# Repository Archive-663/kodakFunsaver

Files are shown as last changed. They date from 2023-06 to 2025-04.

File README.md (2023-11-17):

# Lot no.004 | A Rehousing for Kodak Funsaver Lenses
Unexpect the Expected. digi-Process C-41 Lens Adapter for Kodak Funsaver

The Loudness of Noise

You hate waiting for film to be processed and wish it was instant. But I want that analogue feel without the analogue burden.

I keep these memories, looking through old photos with a wash of nostalgia. Each tell a different story, but the same one every time.

The photographs, while taken quickly and blasé, tell a story once only told through cheap disposable cameras. While you think they are poor imitations, I see them as an homage to a time when we were children documenting our family trips. This lens adapter is a return to our childlike innocence and spontaneity.

The loudness of noise is a link to the past. A link to a time when we waited for the one hour film developer to process our memories.

Nostalgia — it sells.

### Features:
- Breech-lock mounting ring for DSLR/SLR cameras
- Standard mounting for Mirrorless cameras
- 30mm focal length
- Fixed ~f11 aperture
- Available in: Canon EF, EF-S, FD, RF; Fuji X; Leica M; M42; Nikon F DX, F FX, Z FX; Sony E, FE

### Helpful Links:
- [Kodak FunSaver Disassembly](https://www.youtube.com/watch?v=eMyq5sUIDkU)

- [Kodak FunSaver Lens Removal](https://www.youtube.com/watch?v=mniP1P2PrpM)

- [Kodak FunSaver Lens Adapter Assembly](https://www.youtube.com/watch?v=7Ed5-oDCAb8)

### Help support Archive 663 with a dontation or monthly sub


### Samples

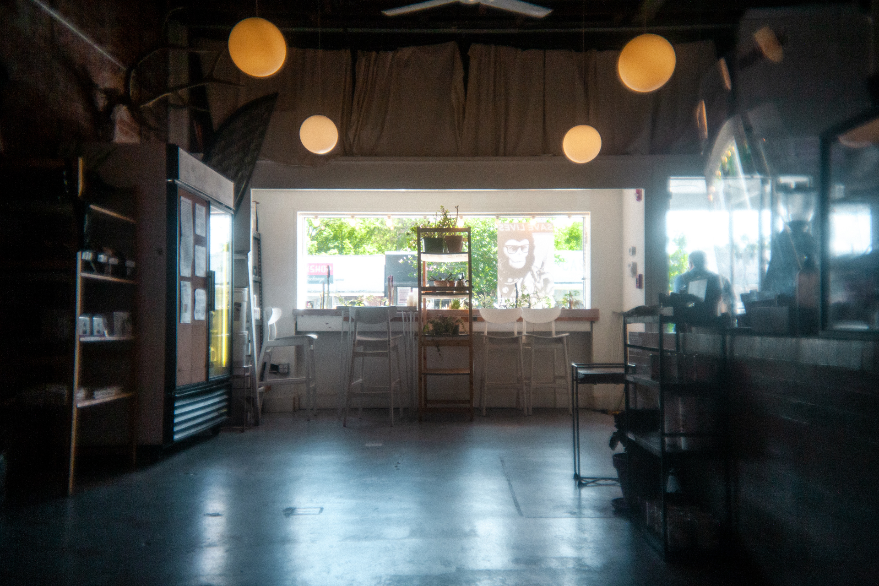
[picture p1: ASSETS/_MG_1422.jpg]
Sample 001

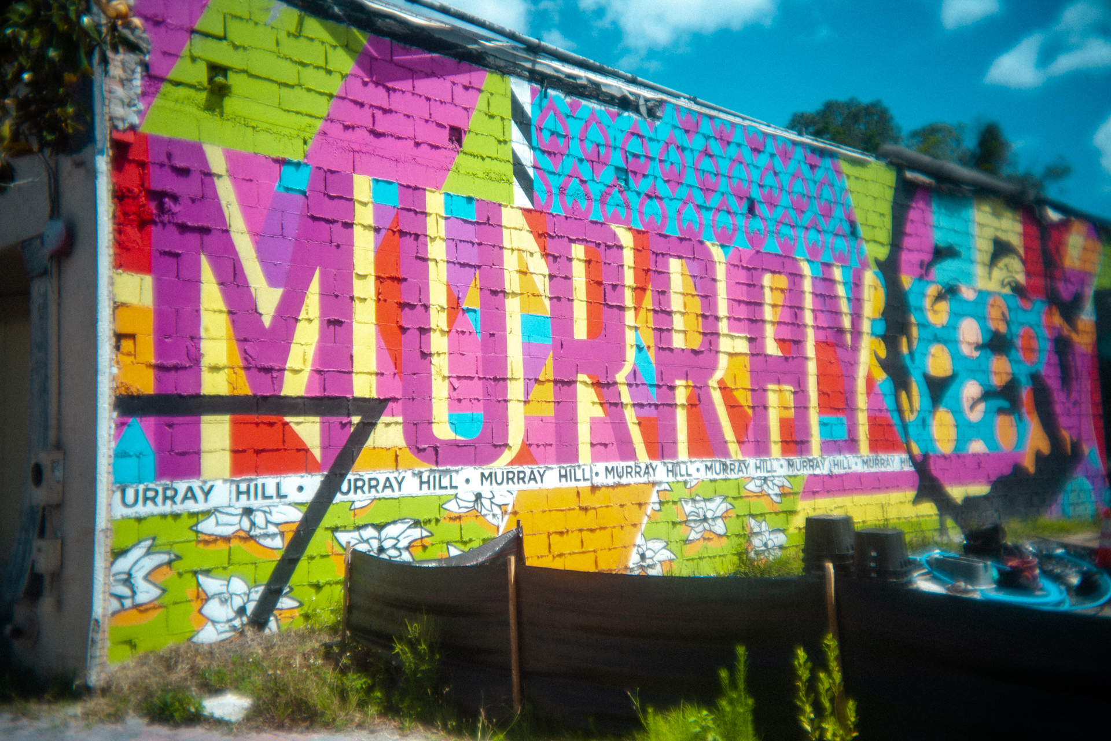
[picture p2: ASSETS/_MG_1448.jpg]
Sample 002

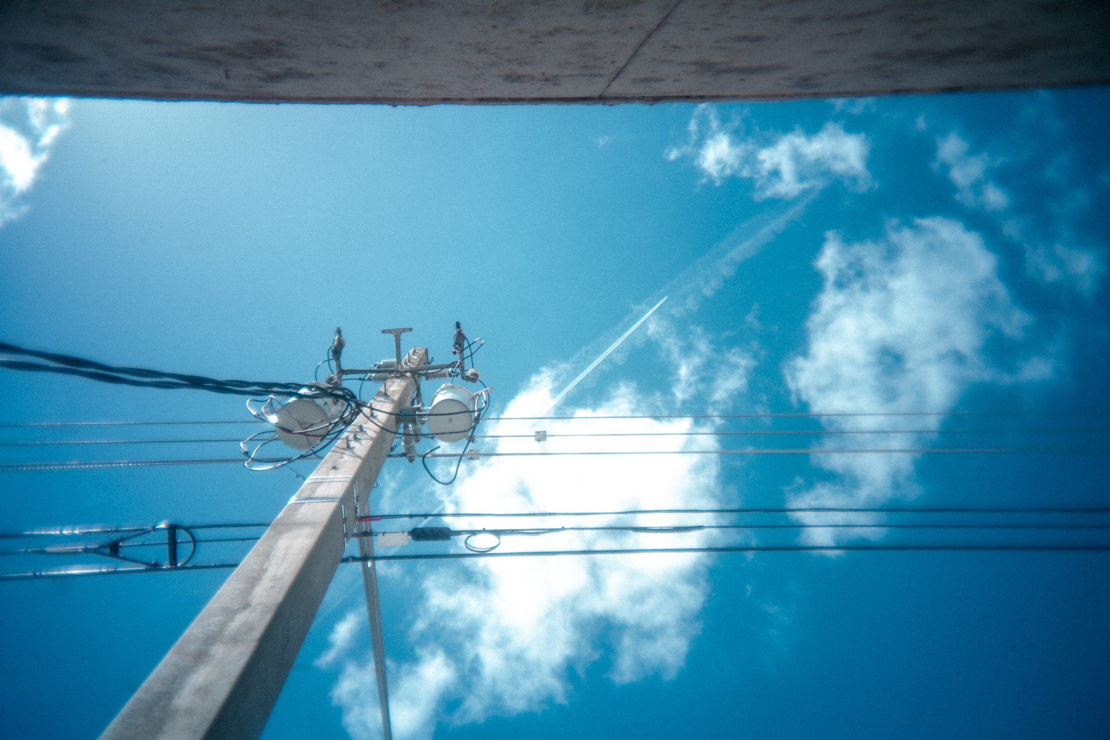
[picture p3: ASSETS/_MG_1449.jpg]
Sample 003

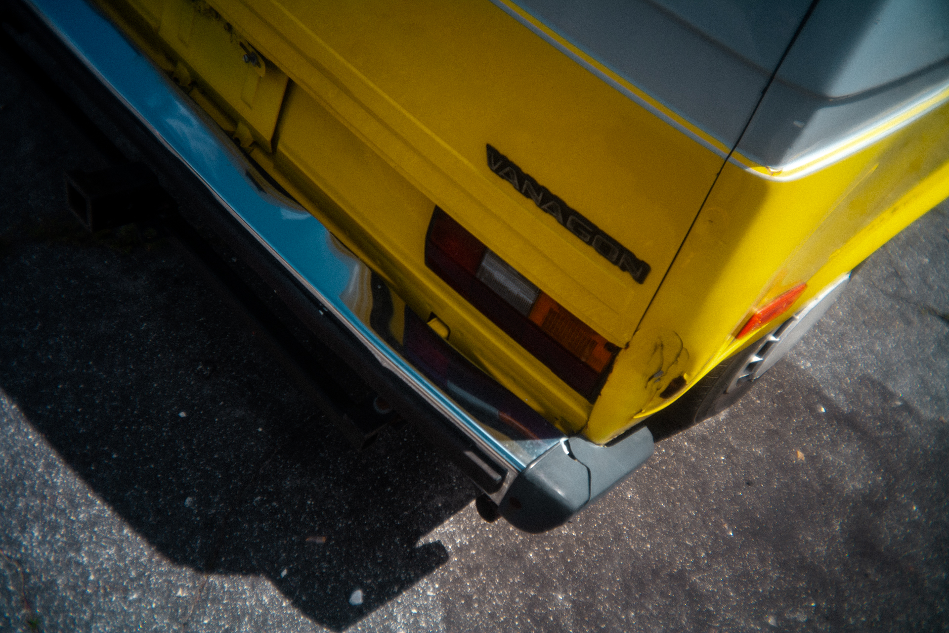
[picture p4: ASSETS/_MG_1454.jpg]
Sample 004

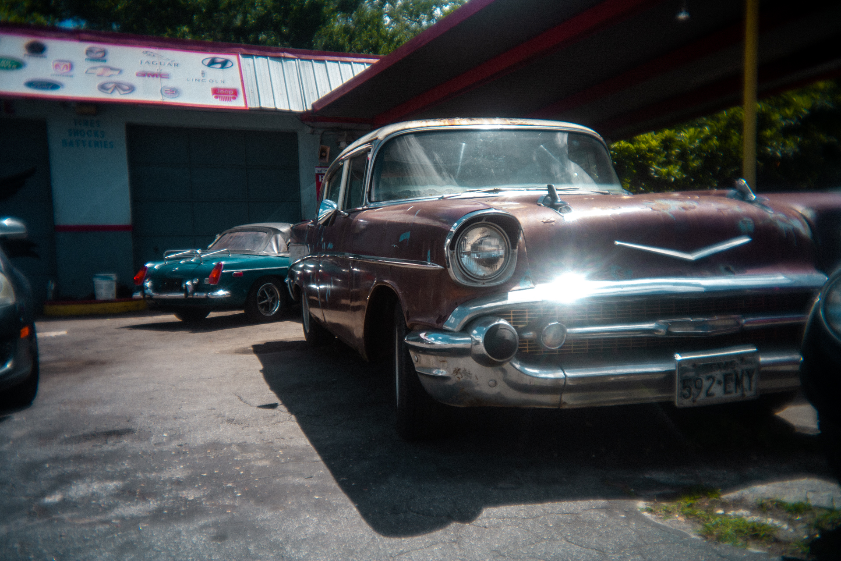
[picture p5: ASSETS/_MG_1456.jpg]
Sample 005

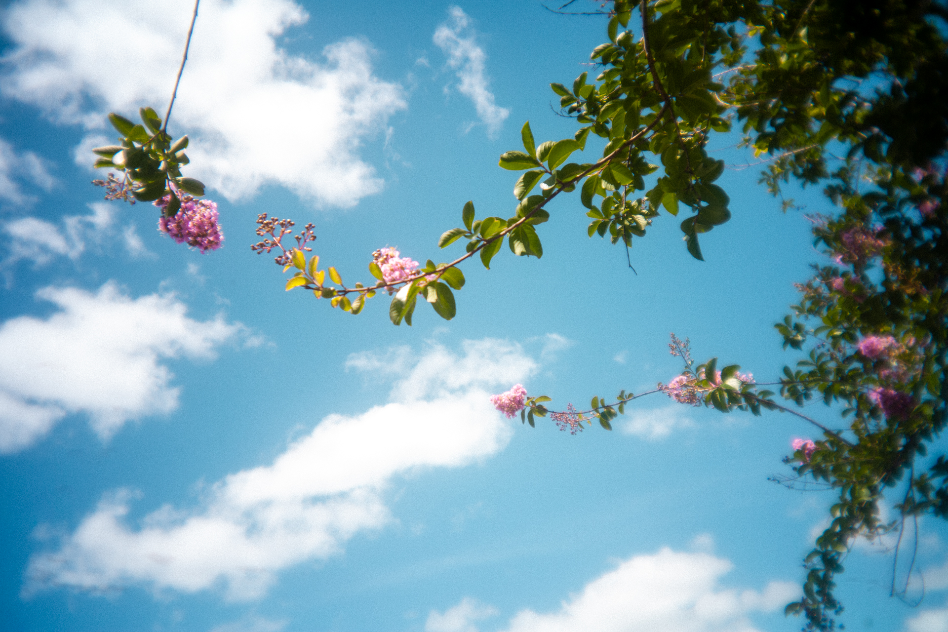
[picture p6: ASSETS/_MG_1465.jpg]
Sample 006

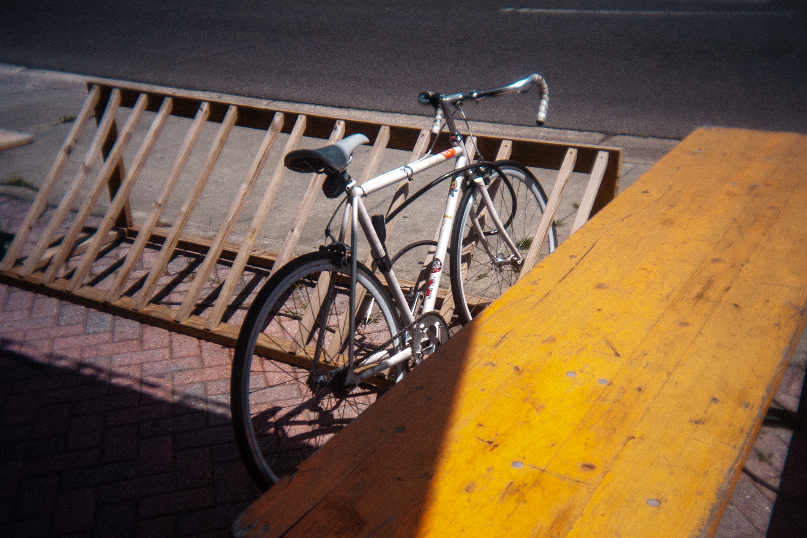
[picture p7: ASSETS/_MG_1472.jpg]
Sample 007

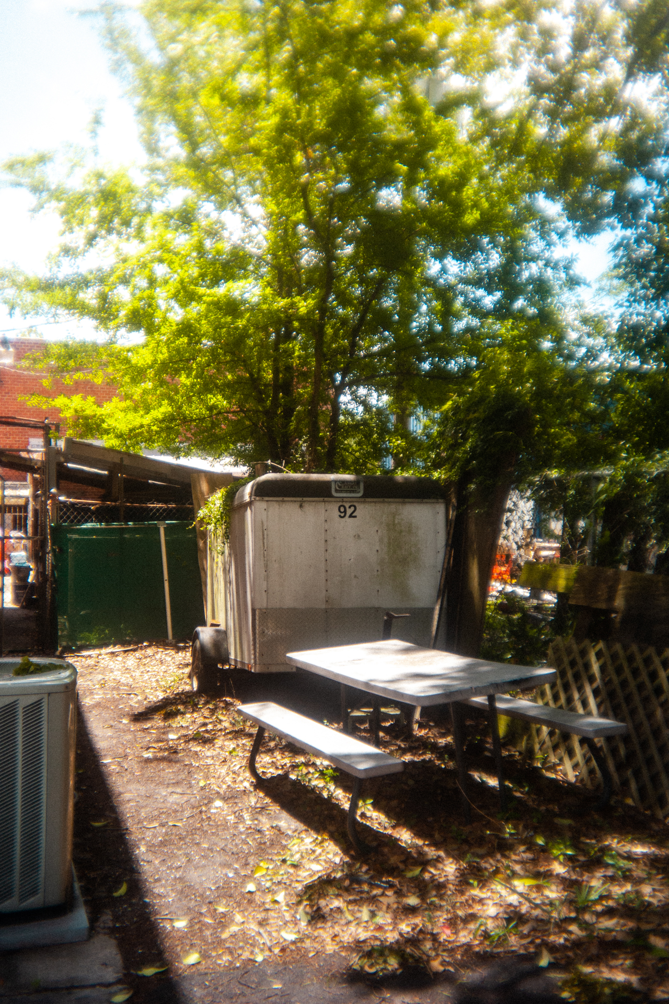
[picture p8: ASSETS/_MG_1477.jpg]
Sample 008


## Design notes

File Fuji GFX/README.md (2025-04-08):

## Kodak Funsaver lens rehousing for Fuji GFX

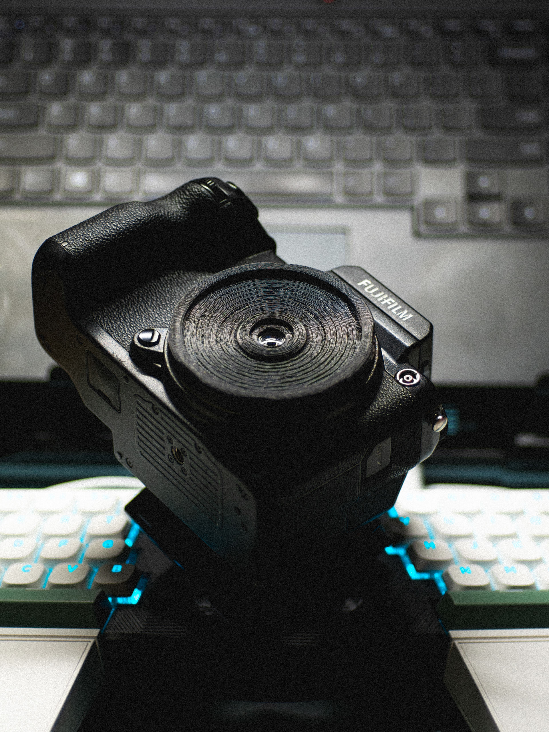
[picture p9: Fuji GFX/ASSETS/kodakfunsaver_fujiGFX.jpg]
KFS_fujiGFX_1


### Features:
- Standard mounting for Mirrorless cameras
- 30mm focal length
- Fixed ~f11 aperture
- Available in: Canon EF, EF-S, FD, RF; Fuji X, GFX; Leica M; M42; Nikon F DX, F FX, Z; Sony E

### What you’ll need:
- Lens from a Kodak FunSaver (2015 and newer)
- Viewfinder lenses from a Kodak FunSaver (2015 or newer) for
  
  [Kodak Funsaver Viewfinder Housing](https://github.com/Archive-663/kodakFunsaver/tree/main/viewFinder)
  
### What would be helpful:
- digi-Process C-41 Lightroom Preset

    [Lightroom Presets](https://github.com/Archive-663/lightroomPresets)

    This preset develops your photos for a flat base reminiscent of old Kodak negative scans. It does not remove the distortion as it is a characteristic of the lens and of the photos that are produced with film. If you want to remove the distortion; set your distortion slider to ~ -12.

### Samples
No Edits
<p float="left">
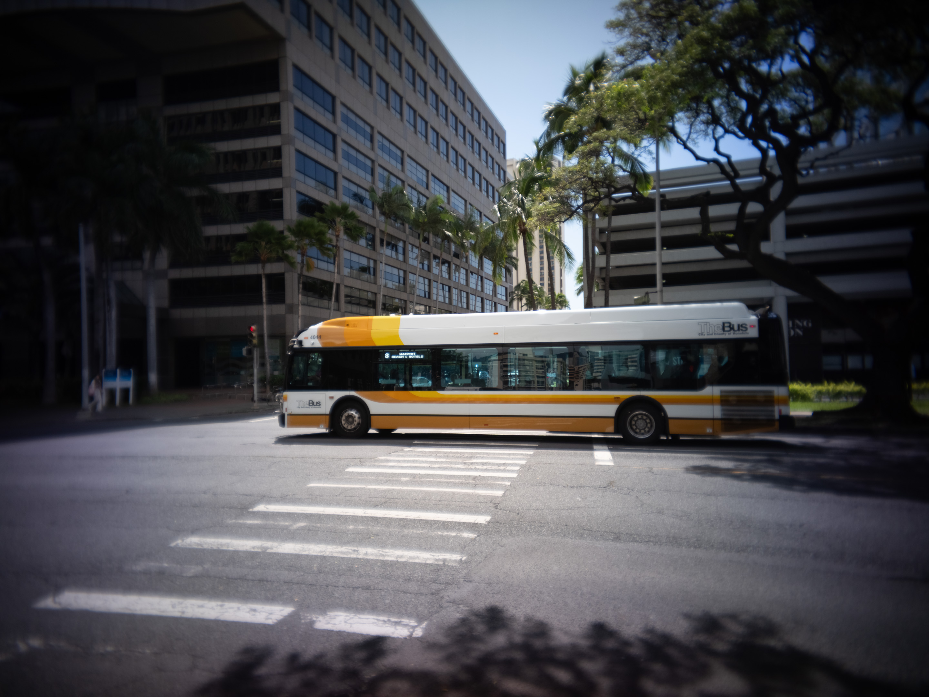
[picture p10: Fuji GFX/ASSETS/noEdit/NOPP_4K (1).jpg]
  
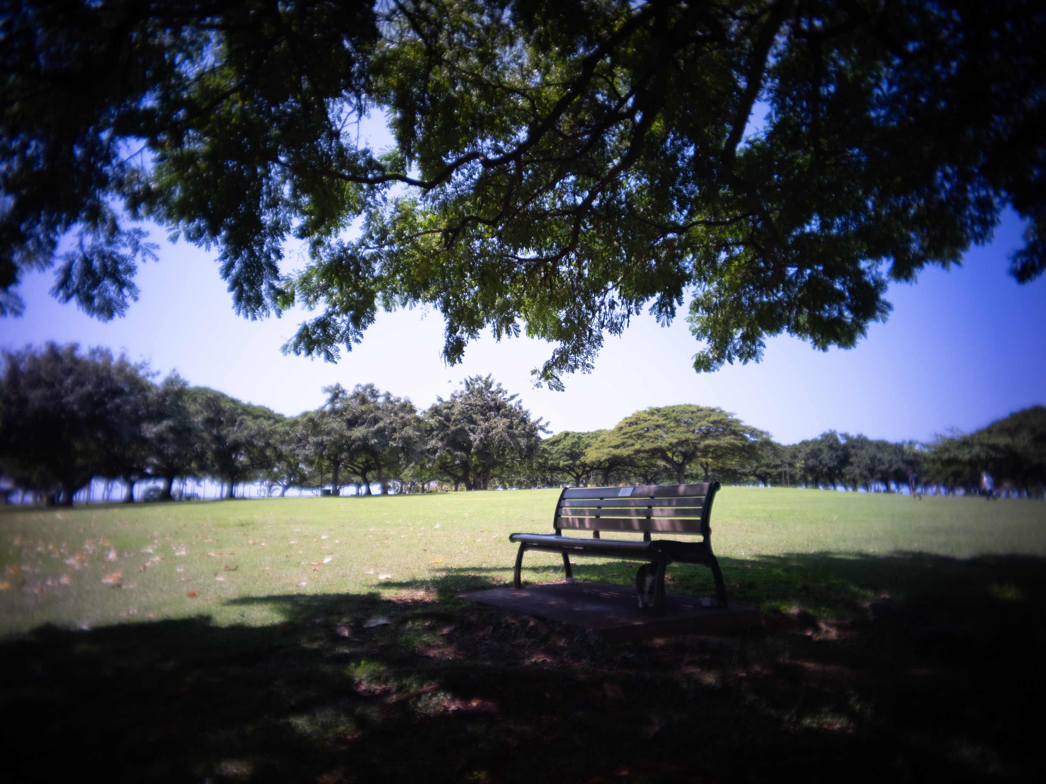
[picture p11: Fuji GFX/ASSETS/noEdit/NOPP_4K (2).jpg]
  
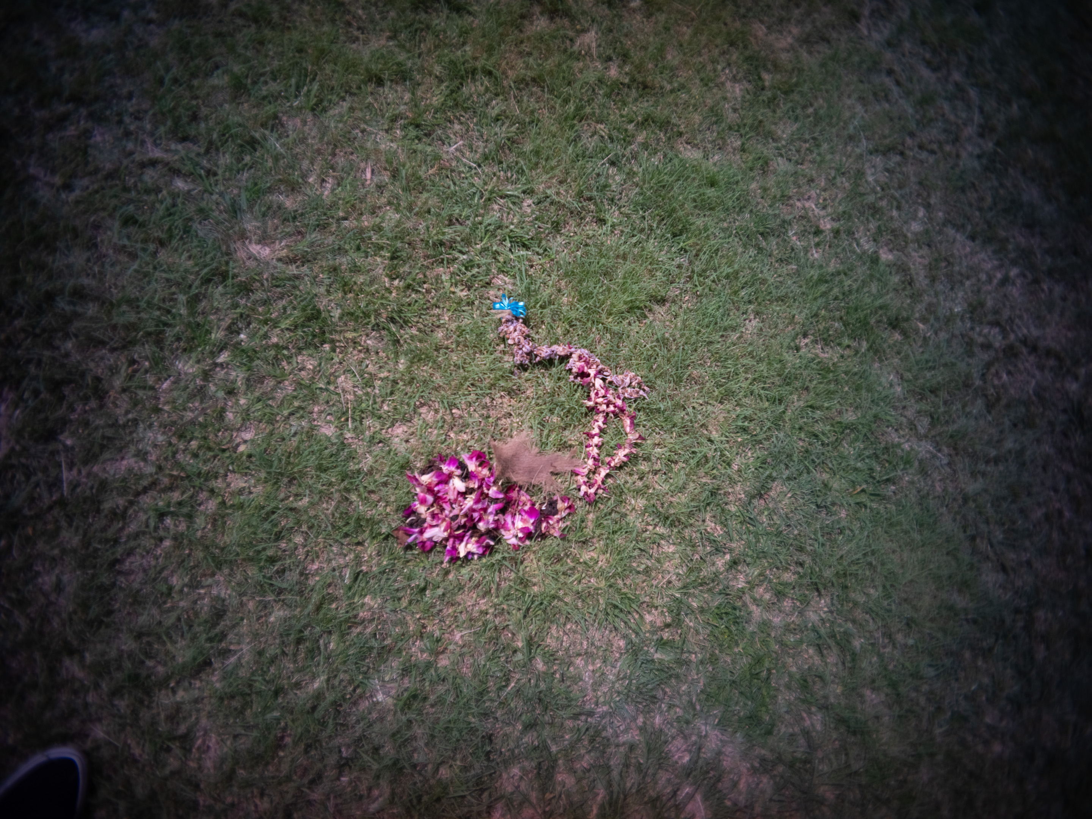
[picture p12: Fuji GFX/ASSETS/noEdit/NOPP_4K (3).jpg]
  
</p>
<p float="left">
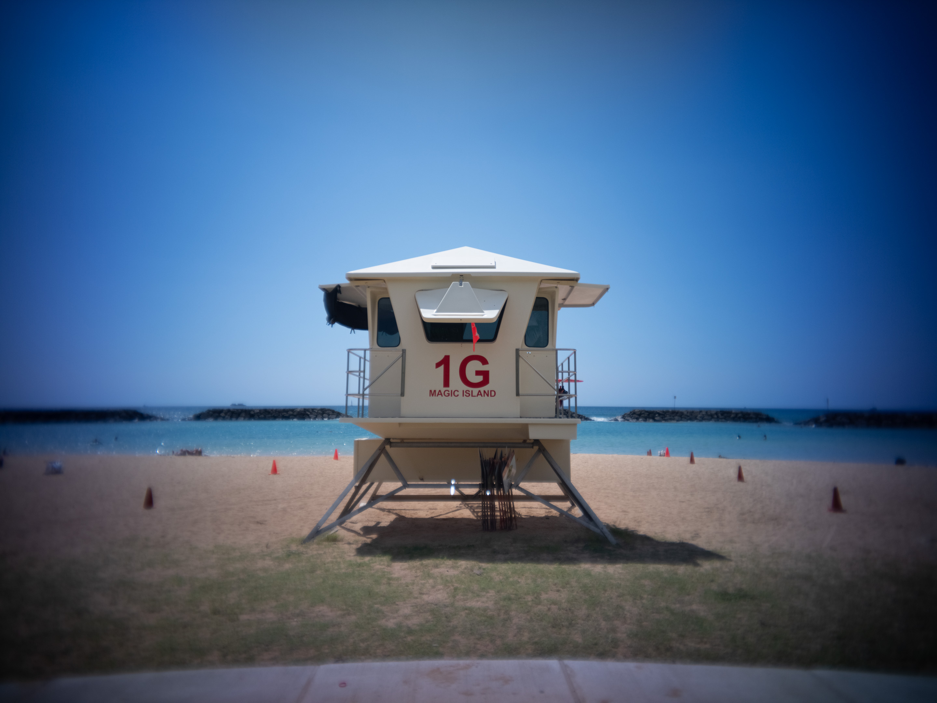
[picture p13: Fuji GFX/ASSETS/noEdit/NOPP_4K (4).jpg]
  
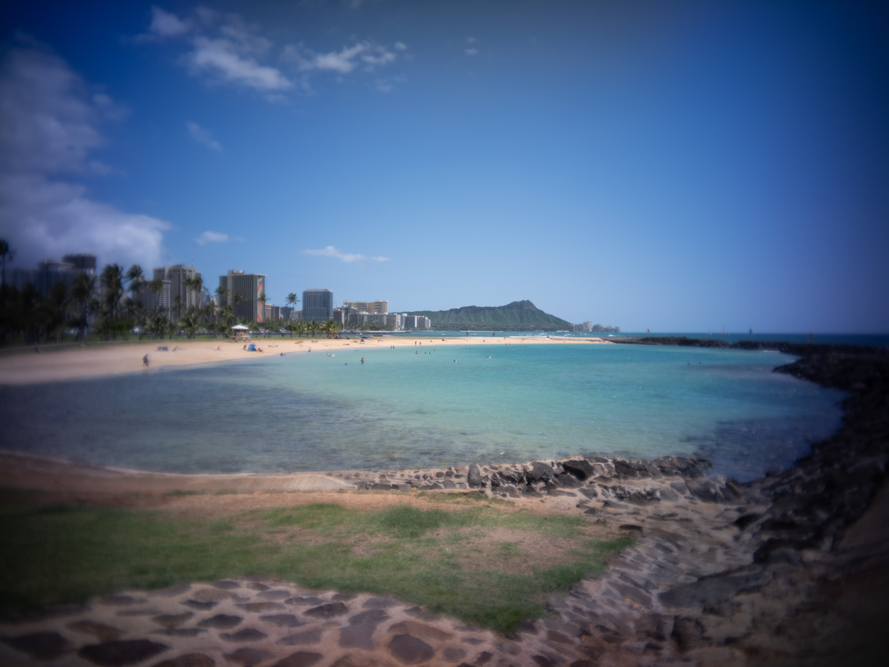
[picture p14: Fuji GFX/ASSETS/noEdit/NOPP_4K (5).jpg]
  
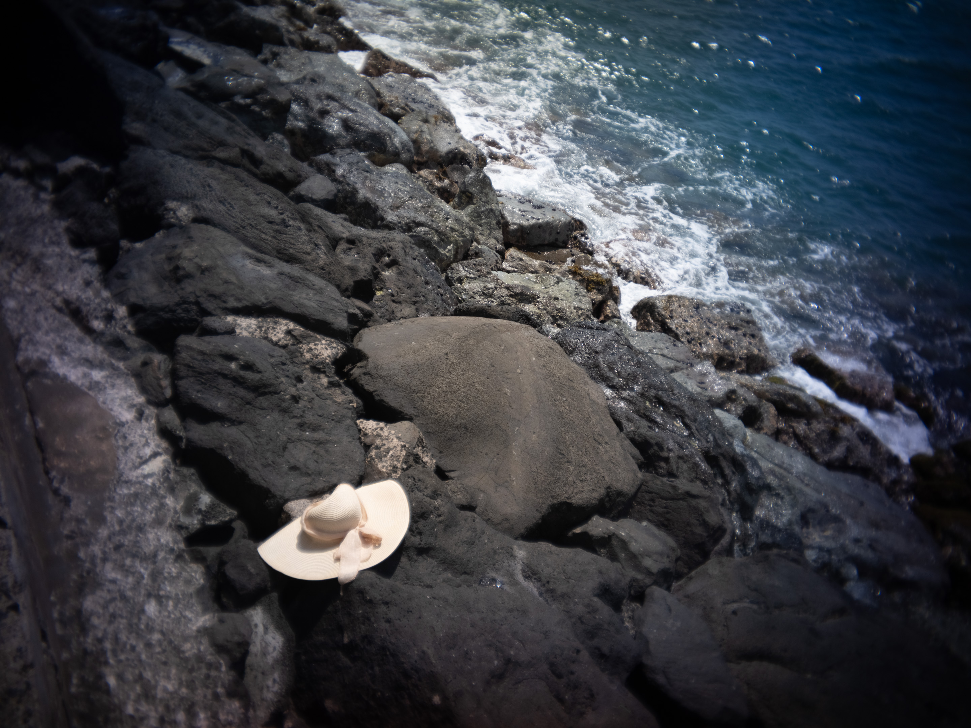
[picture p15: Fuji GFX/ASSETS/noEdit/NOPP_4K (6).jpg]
  
</p>
<p float="left">
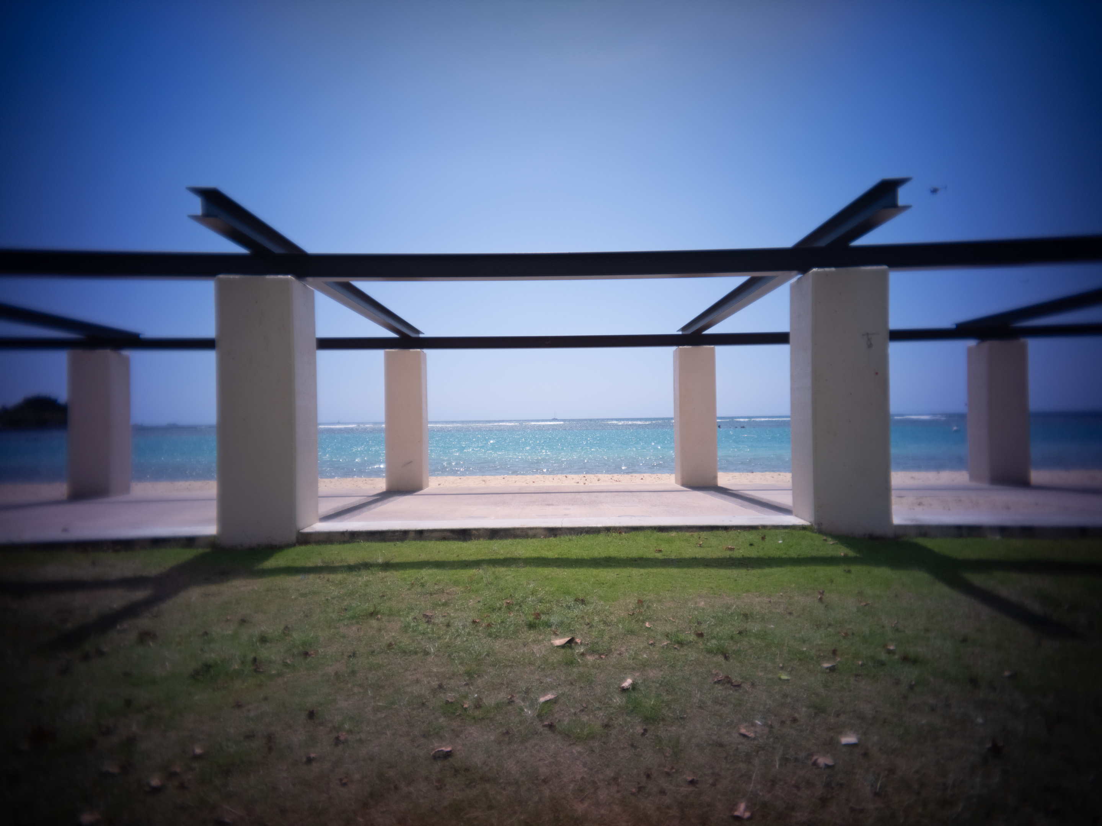
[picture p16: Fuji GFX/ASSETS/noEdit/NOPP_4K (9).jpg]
  
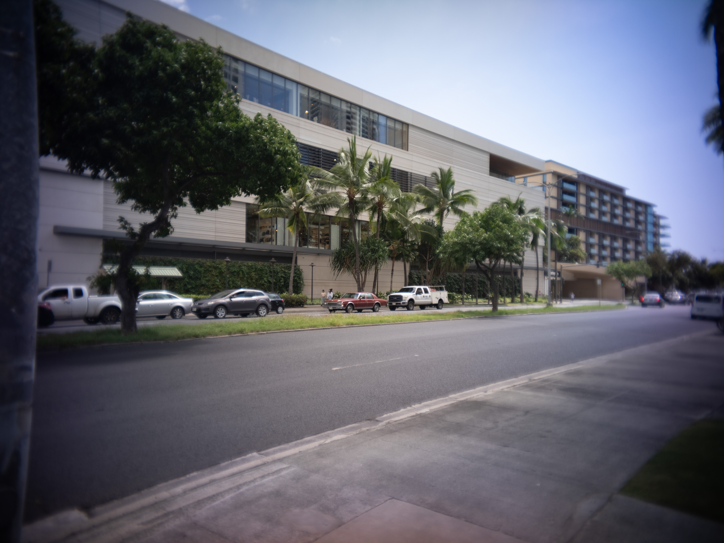
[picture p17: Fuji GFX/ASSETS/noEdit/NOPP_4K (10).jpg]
  
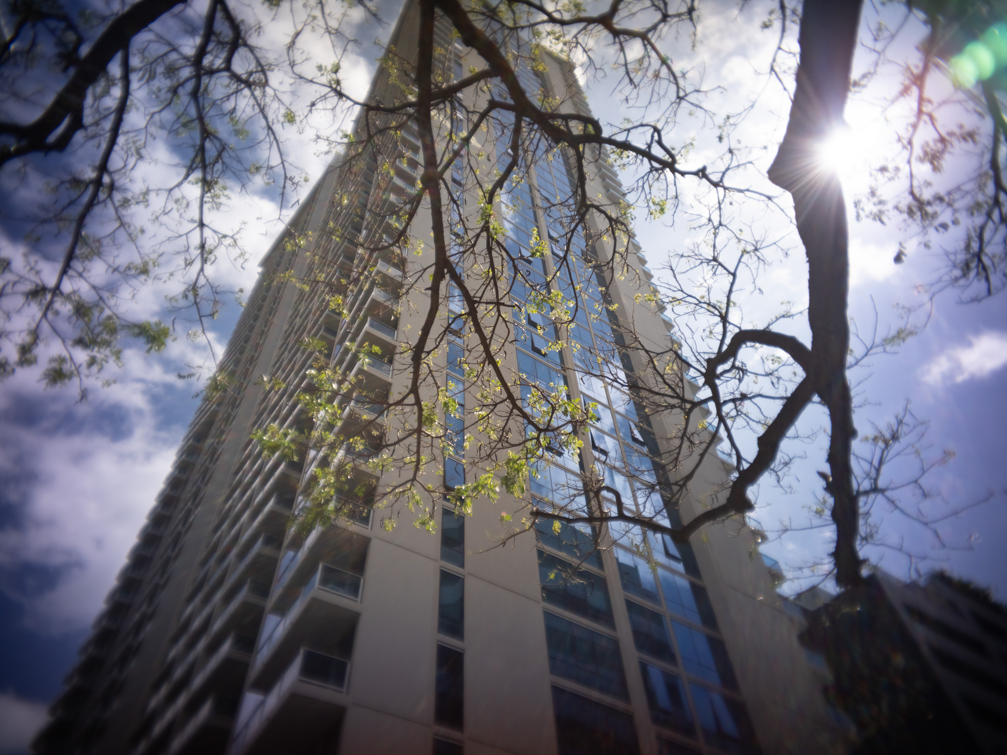
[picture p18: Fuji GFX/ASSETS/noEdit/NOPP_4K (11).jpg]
  
</p>
<p float="left">
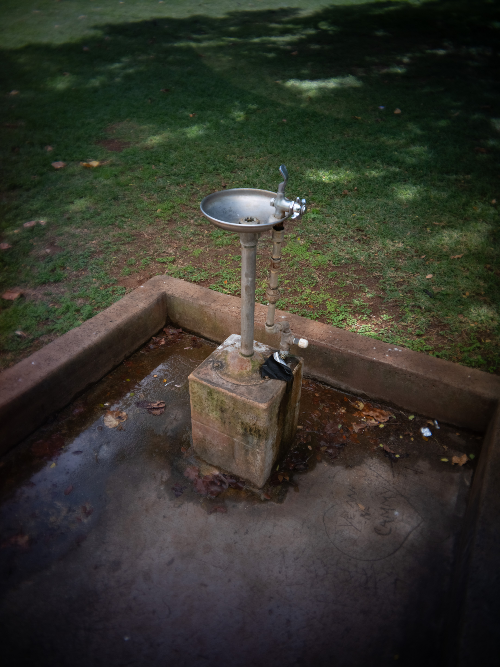
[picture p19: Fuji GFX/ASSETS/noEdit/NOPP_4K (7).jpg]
  
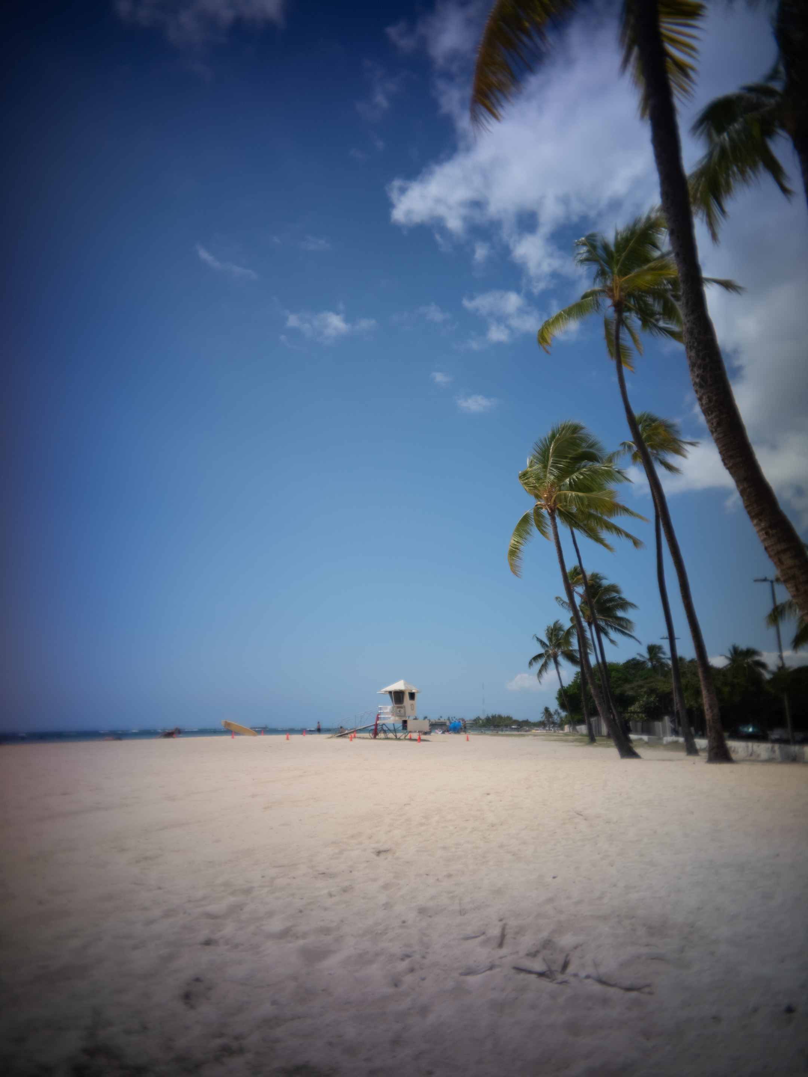
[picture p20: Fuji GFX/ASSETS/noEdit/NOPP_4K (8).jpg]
  
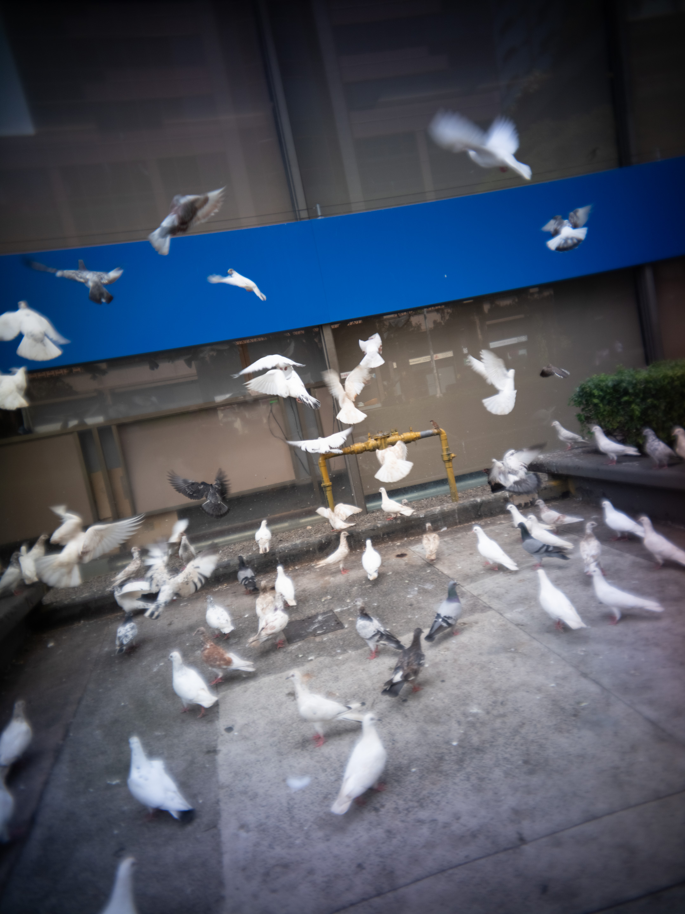
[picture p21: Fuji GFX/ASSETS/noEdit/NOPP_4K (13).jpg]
  
</p>

Post Processed
<p float="left">
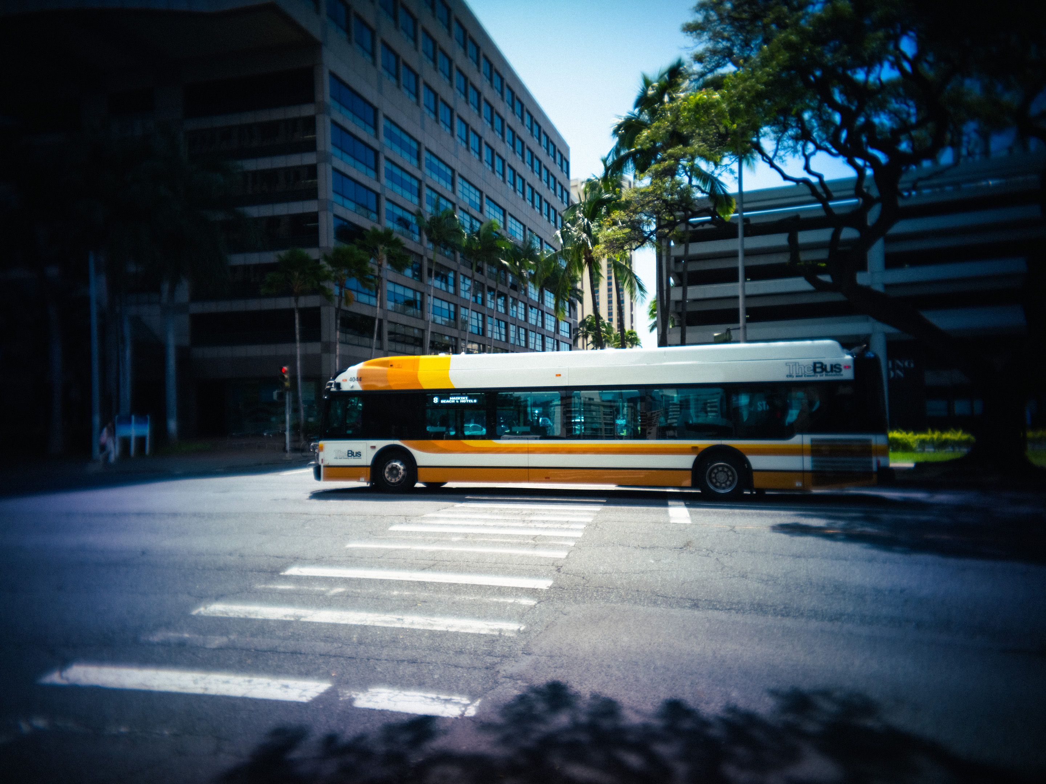
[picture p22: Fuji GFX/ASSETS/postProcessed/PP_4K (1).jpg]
  
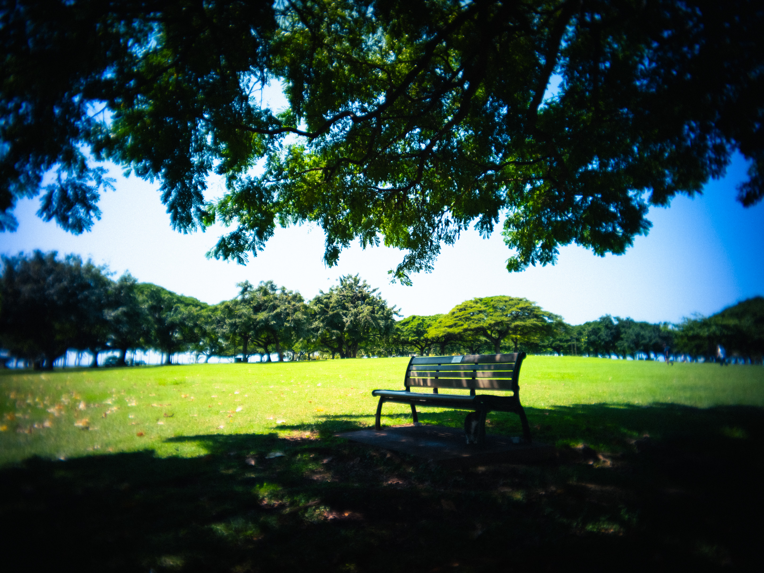
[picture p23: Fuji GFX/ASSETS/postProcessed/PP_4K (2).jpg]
  
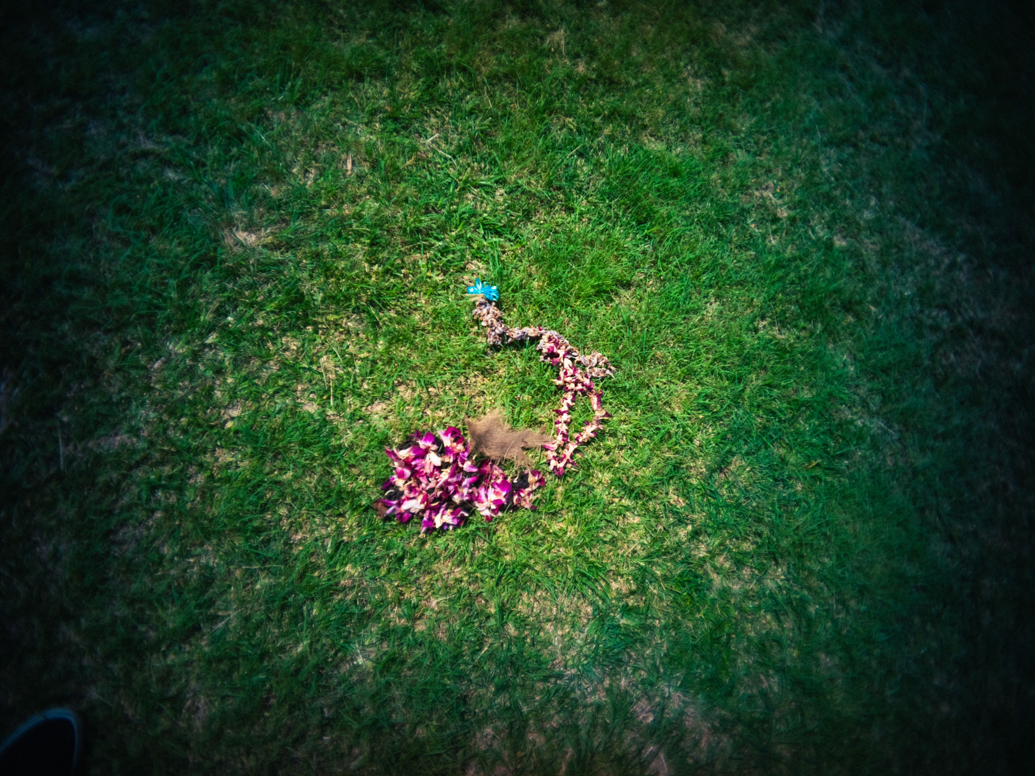
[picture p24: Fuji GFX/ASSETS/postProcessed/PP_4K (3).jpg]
  
</p>
<p float="left">
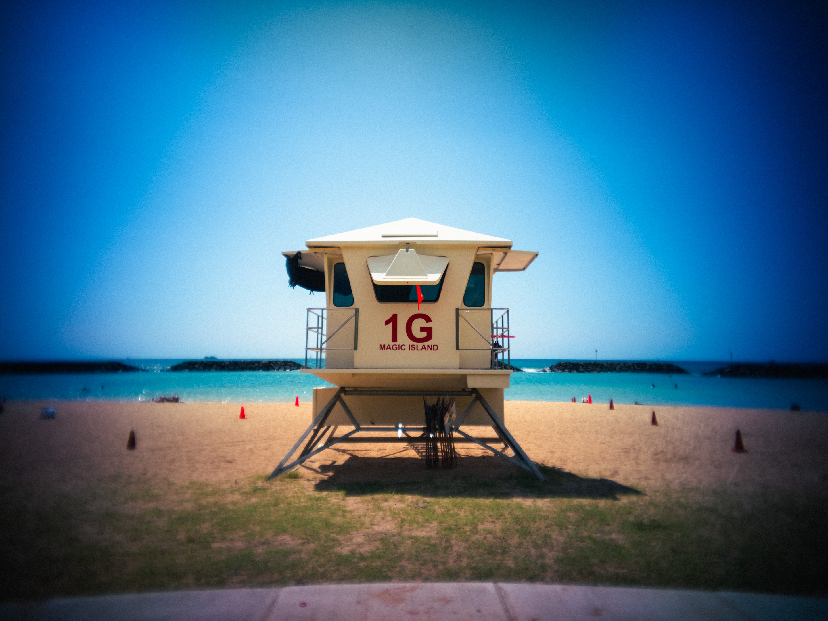
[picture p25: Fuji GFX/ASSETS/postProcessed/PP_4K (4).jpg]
  
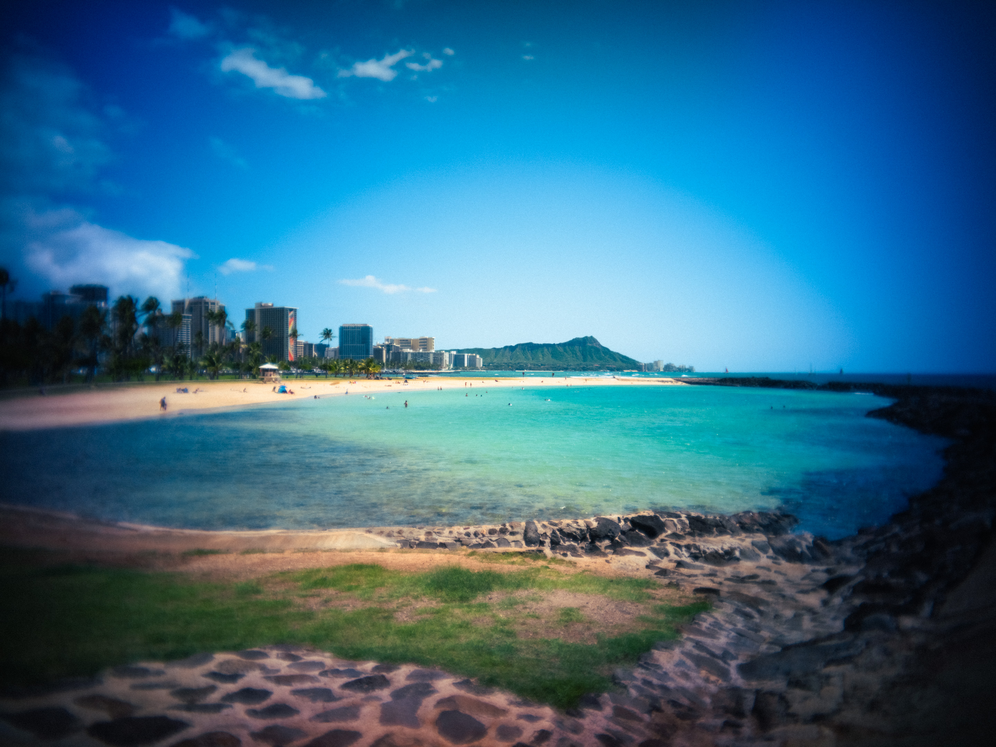
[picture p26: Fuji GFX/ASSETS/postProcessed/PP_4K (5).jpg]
  
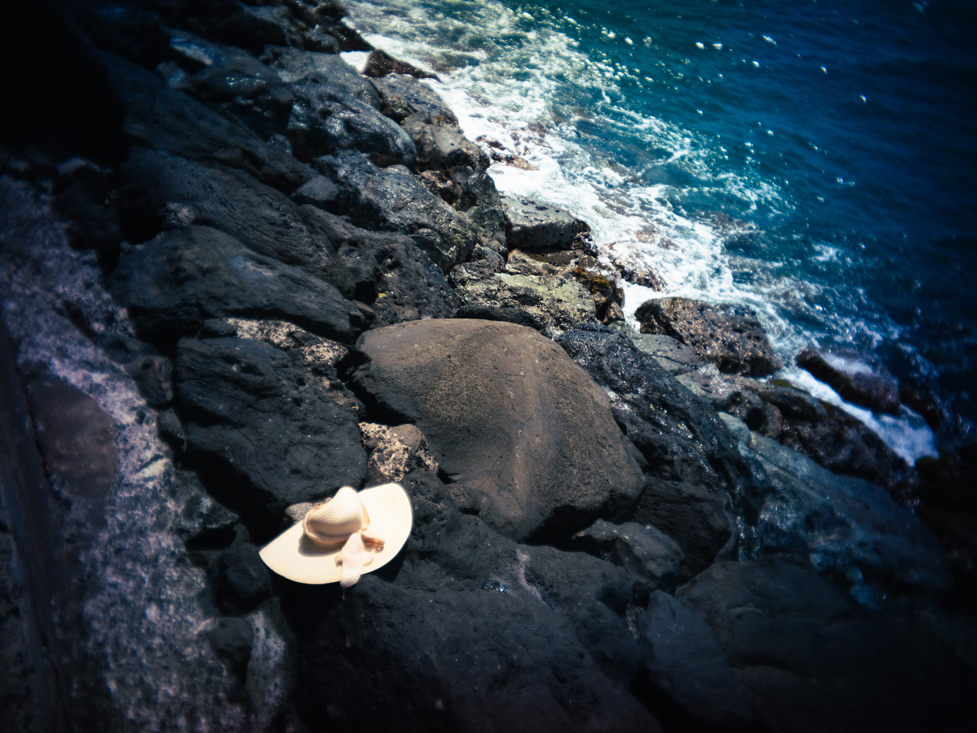
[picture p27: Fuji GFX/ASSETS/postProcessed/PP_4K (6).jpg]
  
</p>
<p float="left">
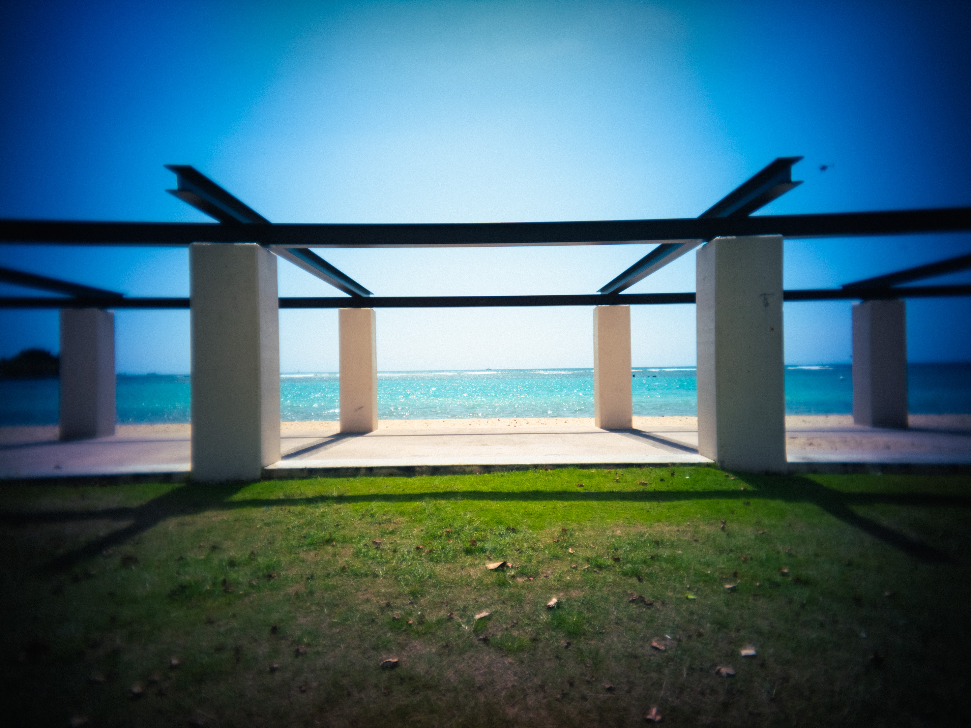
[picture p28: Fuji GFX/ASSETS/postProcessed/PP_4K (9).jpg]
  
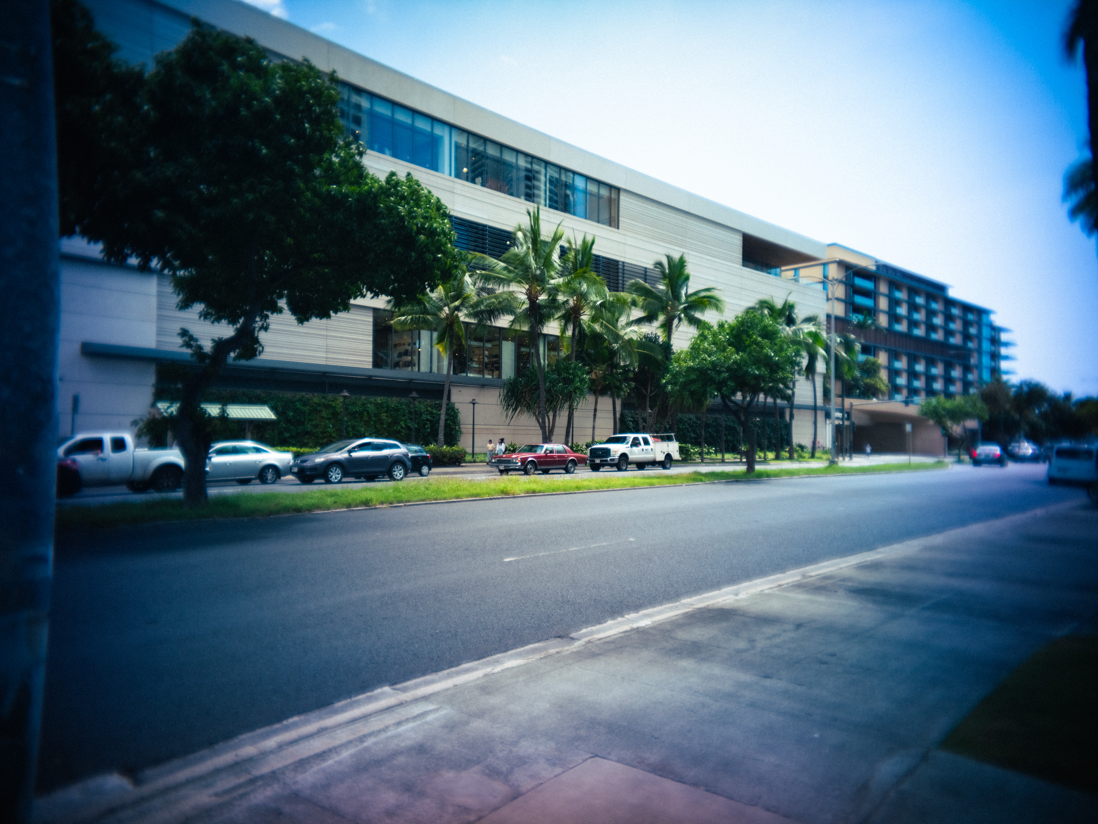
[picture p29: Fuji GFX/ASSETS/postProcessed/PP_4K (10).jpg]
  
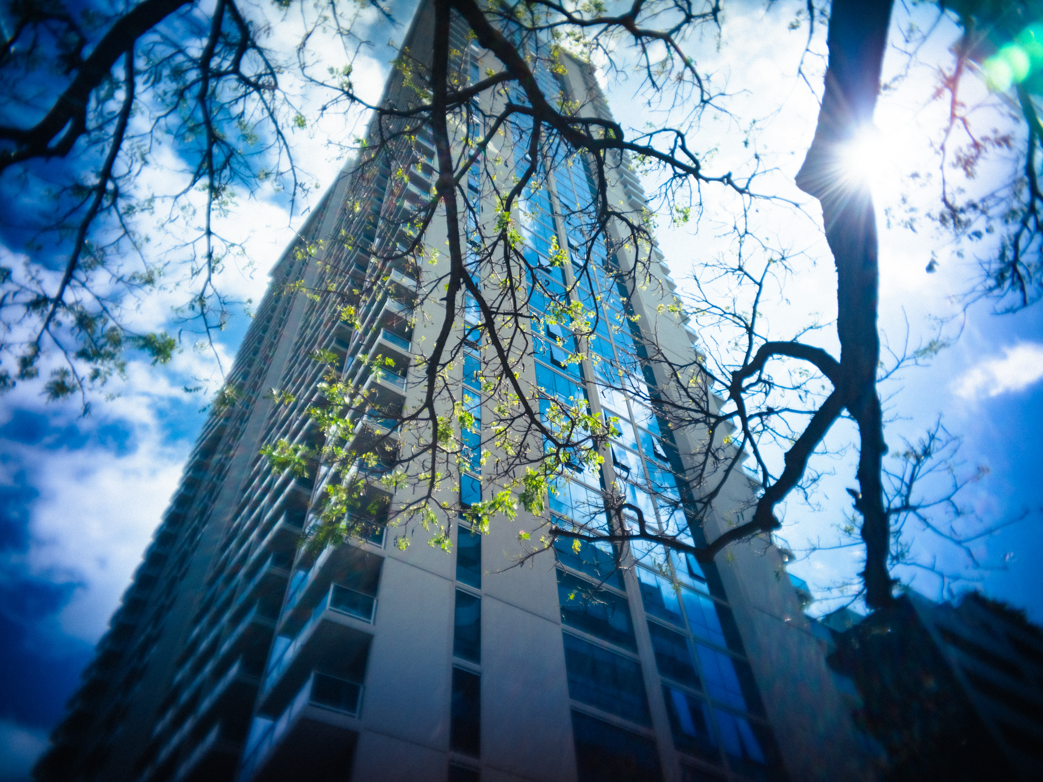
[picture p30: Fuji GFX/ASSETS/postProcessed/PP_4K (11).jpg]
  
</p>
<p float="left">
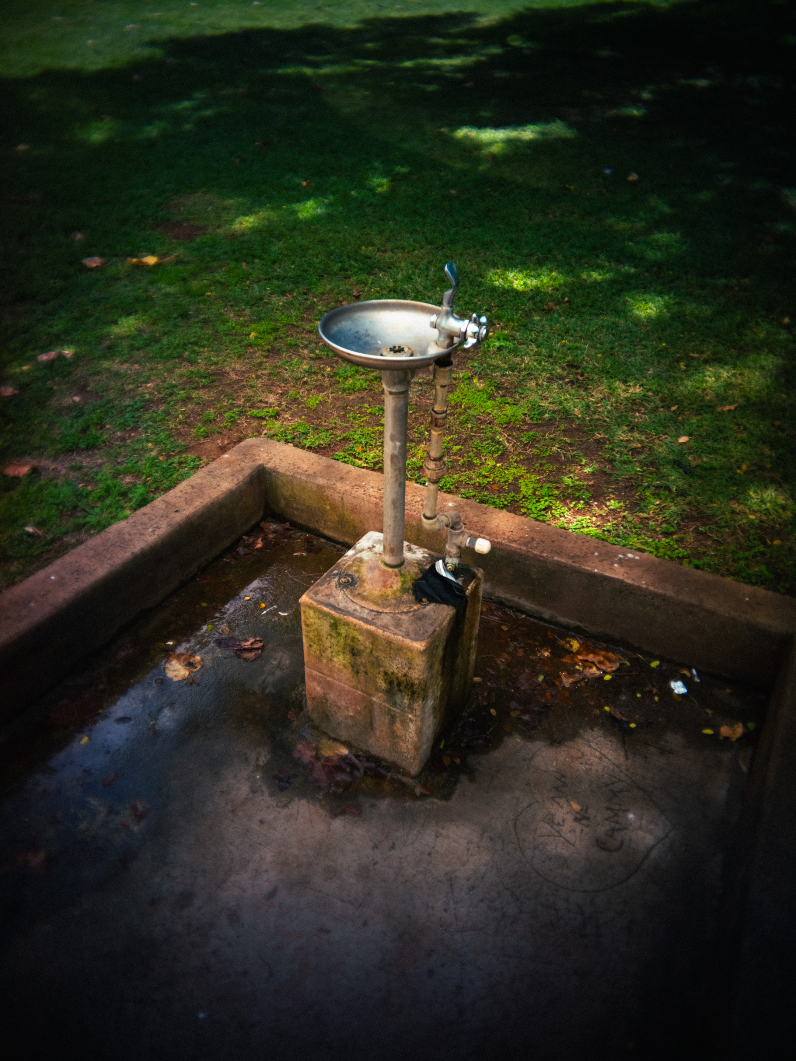
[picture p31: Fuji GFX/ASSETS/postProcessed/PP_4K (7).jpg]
  
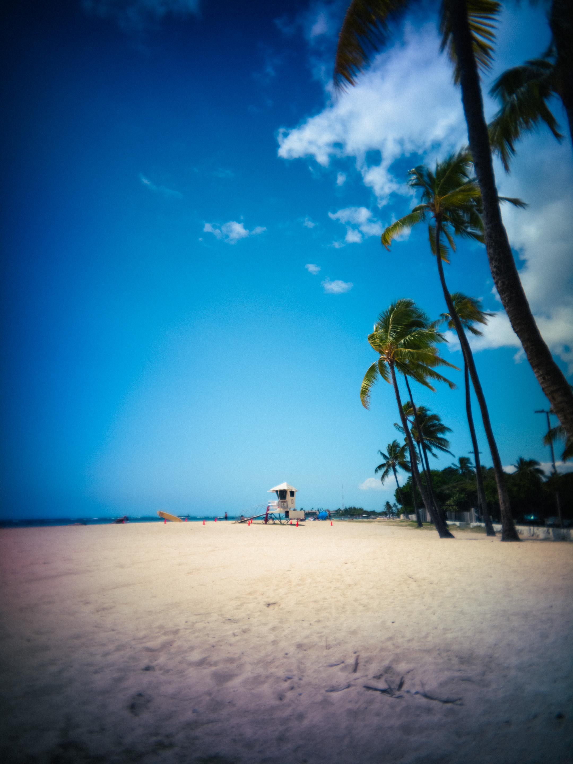
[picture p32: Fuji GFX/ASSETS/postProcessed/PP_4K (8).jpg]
  
  
</p>

### Helpful Links:
- [Kodak FunSaver Disassembly](https://www.youtube.com/watch?v=eMyq5sUIDkU)

- [Kodak FunSaver Lens Removal](https://www.youtube.com/watch?v=mniP1P2PrpM)

- [Kodak FunSaver Lens Adapter Assembly](https://www.youtube.com/watch?v=7Ed5-oDCAb8)

### Printing help:
I print with PETG because it's pretty easy to set up with and dial in. If you want to use something else, go for it. I'd stay away from PLA because it's not the best in heat and against solvents. 

Generally, all my designs have chamfers on the print face of the STL.

Please view the printOrientation.3mf file for help with orienting the parts on the printer bed. 

### Assembly help:
Please view the _assembly.stp file for help in parts orientation. If you do not have a CAD program, <a href="https://www.freecad.org/downloads.php" target="_blank">download FreeCAD</a> to view the assembly file and better understand how it should assemble.

### Help support Archive 663 with a dontation or monthly sub


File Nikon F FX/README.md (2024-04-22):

## Kodak Funsaver lens rehousing for Nikon F FX

KFS_nikonF_FX_1
KFS_nikonF_FX_2
KFS_nikonF_FX_3

### Features:
- Breech-lock mounting ring for DSLR/SLR cameras
- Standard mounting for Mirrorless cameras
- 30mm focal length
- Fixed ~f11 aperture
- Available in: Canon EF, EF-S, FD, RF; Fuji X; Leica M; M42; Nikon F DX, F FX, Z; Sony E

### Compatibility Note:
You need a Nikon F body that allows for mirror lock up. Some newer F FX cameras may not allow mirror lock up with something in the path of the mirror. Just make sure you have mirror lock up. Tested on a Nikon D700.

### What you’ll need:
- A few of M1.6 x 5mm machine screws (PETG)
  or
- A few of M1.6 x 5mm self tapping screws (PETG or ABS)
- Lens from a Kodak FunSaver (2015 and newer)
- Viewfinder lenses from a Kodak FunSaver (2015 or newer) for
  
  [Kodak Funsaver Viewfinder Housing](https://github.com/Archive-663/kodakFunsaver/tree/main/viewFinder)
  
- [49mm Lens Cap](https://github.com/Archive-663/lensCaps)

### What would be helpful:
- M1.4 drill bit
- M1.8/M2 drill bit
- digi-Process C-41 Lightroom Preset

    [Lightroom Presets](https://github.com/Archive-663/lightroomPresets)

    This preset develops your photos for a flat base reminiscent of old Kodak negative scans. It does not remove the distortion as it is a characteristic of the lens and of the photos that are produced with film. If you want to remove the distortion; set your distortion slider to ~ -12.

### Helpful Links:
- [Kodak FunSaver Disassembly](https://www.youtube.com/watch?v=eMyq5sUIDkU)

- [Kodak FunSaver Lens Removal](https://www.youtube.com/watch?v=mniP1P2PrpM)

- [Kodak FunSaver Lens Adapter Assembly](https://www.youtube.com/watch?v=7Ed5-oDCAb8)

### Printing help:
I print with PETG because it's pretty easy to set up with and dial in. If you want to use something else, go for it. I'd stay away from PLA because it's not the best in heat and against solvents. 

Generally, all my designs have chamfers on the print face of the STL.

Please view the printOrientation.3mf file for help with orienting the parts on the printer bed. 

### Assembly help:
I suggest drilling holds to their correct tap size before tapping. The m1.6 holes should be drilled out to 1.4 then tapped with the m1.6 tap. The Rotator holes should be drilled out with an m2 or m1.8 drill bit.

When assembling the rotating assemblies use some synthetic grease similar to Super Lube PTFE or keycap lube to make the rotate function smoother. 

Please view the _assembly.stp file for help in parts orientation. If you do not have a CAD program, <a href="https://www.freecad.org/downloads.php" target="_blank">download FreeCAD</a> to view the assembly file and better understand how it should assemble.

### Help support Archive 663 with a dontation or monthly sub


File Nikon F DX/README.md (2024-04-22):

## Kodak Funsaver lens rehousing for Nikon F DX

KFS_nikonF_DX_1
KFS_nikonF_DX_2
KFS_nikonF_DX_3

### Features:
- Breech-lock mounting ring for DSLR/SLR cameras
- Standard mounting for Mirrorless cameras
- 30mm focal length
- Fixed ~f11 aperture
- Available in: Canon EF, EF-S, FD, RF; Fuji X; Leica M; M42; Nikon F DX, F FX, Z; Sony E

### Compatibility Note:
You need a Nikon F body that allows for mirror lock up. Some newer F DX cameras may not allow mirror lock up with something in the path of the mirror. Just make sure you have mirror lock up. Tested on a Nikon D200.

### What you’ll need:
- A few of M1.6 x 5mm machine screws (PETG)
  or
- A few of M1.6 x 5mm self tapping screws (PETG or ABS)
- Lens from a Kodak FunSaver (2015 and newer)
- Viewfinder lenses from a Kodak FunSaver (2015 or newer) for
  
  [Kodak Funsaver Viewfinder Housing](https://github.com/Archive-663/kodakFunsaver/tree/main/viewFinder)
  
- [49mm Lens Cap](https://github.com/Archive-663/lensCaps)

### What would be helpful:
- M1.4 drill bit
- M1.8/M2 drill bit
- digi-Process C-41 Lightroom Preset

    [Lightroom Presets](https://github.com/Archive-663/lightroomPresets)

    This preset develops your photos for a flat base reminiscent of old Kodak negative scans. It does not remove the distortion as it is a characteristic of the lens and of the photos that are produced with film. If you want to remove the distortion; set your distortion slider to ~ -12.

### Helpful Links:
- [Kodak FunSaver Disassembly](https://www.youtube.com/watch?v=eMyq5sUIDkU)

- [Kodak FunSaver Lens Removal](https://www.youtube.com/watch?v=mniP1P2PrpM)

- [Kodak FunSaver Lens Adapter Assembly](https://www.youtube.com/watch?v=7Ed5-oDCAb8)

### Printing help:
I print with PETG because it's pretty easy to set up with and dial in. If you want to use something else, go for it. I'd stay away from PLA because it's not the best in heat and against solvents. 

Generally, all my designs have chamfers on the print face of the STL.

Please view the printOrientation.3mf file for help with orienting the parts on the printer bed. 

### Assembly help:
I suggest drilling holds to their correct tap size before tapping. The m1.6 holes should be drilled out to 1.4 then tapped with the m1.6 tap. The Rotator holes should be drilled out with an m2 or m1.8 drill bit.

When assembling the rotating assemblies use some synthetic grease similar to Super Lube PTFE or keycap lube to make the rotate function smoother. 

Please view the _assembly.stp file for help in parts orientation. If you do not have a CAD program, <a href="https://www.freecad.org/downloads.php" target="_blank">download FreeCAD</a> to view the assembly file and better understand how it should assemble.

### Help support Archive 663 with a dontation or monthly sub


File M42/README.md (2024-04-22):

## Kodak Funsaver lens rehousing for M42

KFS_M42_1
KFS_M42_2
KFS_M42_3

### Features:
- Breech-lock mounting ring for DSLR/SLR cameras
- Standard mounting for Mirrorless cameras
- 30mm focal length
- Fixed ~f11 aperture
- Available in: Canon EF, EF-S, FD, RF; Fuji X; Leica M; M42; Nikon F DX, F FX, Z; Sony E

### Compatibility Note:
You need an M42 body that allows for mirror lock up. Some older film cameras allowed you to hold the mirror up with hardware, but there are some that link the mirror actuation to the shutter actuation so you can't lock your mirror up. Just make sure you have mirror lock up. Tested on a Sears TLS. Granted the TLS doesn't have mirror lock up, I manually locked the mirror up with the lens. In this configuration the shutter fires once the film advance lever is release. So instead of film advance, compose shot, presss shutter button. It's compose shot, actuate the film advance lever, and the shutter fires once the film advance lever is released. 

### What you’ll need:
- A few of M1.6 x 5mm machine screws (PETG)
  or
- A few of M1.6 x 5mm self tapping screws (PETG or ABS)
- Lens from a Kodak FunSaver (2015 and newer)
- Viewfinder lenses from a Kodak FunSaver (2015 or newer) for
  
  [Kodak Funsaver Viewfinder Housing](https://github.com/Archive-663/kodakFunsaver/tree/main/viewFinder)
  
- [49mm Lens Cap](https://github.com/Archive-663/lensCaps)

### What would be helpful:
- M1.4 drill bit
- M1.8/M2 drill bit
- digi-Process C-41 Lightroom Preset

    [Lightroom Presets](https://github.com/Archive-663/lightroomPresets)

    This preset develops your photos for a flat base reminiscent of old Kodak negative scans. It does not remove the distortion as it is a characteristic of the lens and of the photos that are produced with film. If you want to remove the distortion; set your distortion slider to ~ -12.

### Helpful Links:
- [Kodak FunSaver Disassembly](https://www.youtube.com/watch?v=eMyq5sUIDkU)

- [Kodak FunSaver Lens Removal](https://www.youtube.com/watch?v=mniP1P2PrpM)

- [Kodak FunSaver Lens Adapter Assembly](https://www.youtube.com/watch?v=7Ed5-oDCAb8)

### Printing help:
I print with PETG because it's pretty easy to set up with and dial in. If you want to use something else, go for it. I'd stay away from PLA because it's not the best in heat and against solvents. 

Generally, all my designs have chamfers on the print face of the STL.

Please view the printOrientation.3mf file for help with orienting the parts on the printer bed. 

### Assembly help:
I suggest drilling holds to their correct tap size before tapping. The m1.6 holes should be drilled out to 1.4 then tapped with the m1.6 tap. The Rotator holes should be drilled out with an m2 or m1.8 drill bit.

When assembling the rotating assemblies use some synthetic grease similar to Super Lube PTFE or keycap lube to make the rotate function smoother. 

Please view the _assembly.stp file for help in parts orientation. If you do not have a CAD program, <a href="https://www.freecad.org/downloads.php" target="_blank">download FreeCAD</a> to view the assembly file and better understand how it should assemble.

### Help support Archive 663 with a dontation or monthly sub


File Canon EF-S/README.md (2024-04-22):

## Kodak Funsaver lens rehousing for Canon EF-S

KFS_canonEF-S_1
KFS_canonEF-S_2
KFS_canonEF-S_3

### Features:
- Breech-lock mounting ring for DSLR/SLR cameras
- Standard mounting for Mirrorless cameras
- 30mm focal length
- Fixed ~f11 aperture
- Available in: Canon EF, EF-S, FD, RF; Fuji X; Leica M; M42; Nikon F DX, F FX, Z; Sony E

### Compatibility Note:

This lens doesn't work on the newer Canon 5D Mark IV, Canon 6D Mark II, and Canon 1DX series. The firmware on the 5D Mark IV and 6D Mark II both look for the mirror to make its full actuation before firing the shutter. This means we can lock the mirror with hardware to shoot with something like this lens. This lens isn't for the faint of heart, there is some risk of damaging your camera. Tested on a beaten old 5DC. Should work on film, but unconfirmed ATM -- will update. 

Tested on Canon XT + 5D Classic

### What you’ll need:
- A few of M1.6 x 5mm machine screws (PETG)
  or
- A few of M1.6 x 5mm self tapping screws (PETG or ABS)
- Lens from a Kodak FunSaver (2015 and newer)
- Viewfinder lenses from a Kodak FunSaver (2015 or newer) for
  
  [Kodak Funsaver Viewfinder Housing](https://github.com/Archive-663/kodakFunsaver/tree/main/viewFinder)
  
- [49mm Lens Cap](https://github.com/Archive-663/lensCaps)
- An EF-s body with Mirror Lock Up. There may be newer EF-s cameras that don't allow a 'hardware' mirror lock up. I know the Canon 6D (sure an EF camera) doesn't allow you to physically have something locking up the mirror when you take a photo. It will throw up an ERR code and should be reset once you turn the camera off and back on with the lens removed. It has something to do with the firmware and how the camera needs to check if the mirror has fallen back into place or something. But the main take away is that you need to have Mirror Lock up mode enable that stays locked up even after taking a photo. Tested on a Canon XT. 

### What would be helpful:
- M1.4 drill bit
- M1.8/M2 drill bit
- digi-Process C-41 Lightroom Preset

    [Lightroom Presets](https://github.com/Archive-663/lightroomPresets)

    This preset develops your photos for a flat base reminiscent of old Kodak negative scans. It does not remove the distortion as it is a characteristic of the lens and of the photos that are produced with film. If you want to remove the distortion; set your distortion slider to ~ -12.

### Helpful Links:
- [Kodak FunSaver Disassembly](https://www.youtube.com/watch?v=eMyq5sUIDkU)

- [Kodak FunSaver Lens Removal](https://www.youtube.com/watch?v=mniP1P2PrpM)

- [Kodak FunSaver Lens Adapter Assembly](https://www.youtube.com/watch?v=7Ed5-oDCAb8)

### Printing help:
I print with PETG because it's pretty easy to set up with and dial in. If you want to use something else, go for it. I'd stay away from PLA because it's not the best in heat and against solvents. 

Generally, all my designs have chamfers on the print face of the STL.

Please view the printOrientation.3mf file for help with orienting the parts on the printer bed. 

### Assembly help:
I suggest drilling holds to their correct tap size before tapping. The m1.6 holes should be drilled out to 1.4 then tapped with the m1.6 tap. The Rotator holes should be drilled out with an m2 or m1.8 drill bit.

When assembling the rotating assemblies use some synthetic grease similar to Super Lube PTFE or keycap lube to make the rotate function smoother. 

Please view the _assembly.stp file for help in parts orientation. If you do not have a CAD program, <a href="https://www.freecad.org/downloads.php" target="_blank">download FreeCAD</a> to view the assembly file and better understand how it should assemble.

### Help support Archive 663 with a dontation or monthly sub


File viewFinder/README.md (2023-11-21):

## A Rehousing for the Kodak Funsaver Viewfinder

viewFinder_SQ
viewFinder_round

### Features:
- 30ish mm field of view

### What's in this lot:
- Square Version (easier to print and assemble)
- Round Version

### What you’ll need:
- Viewfinder lenses from a Kodak FunSaver (2015 or newer)
- 4x - M1.6 x 5mm self tapping screws (Square version only)

### What would be helpful:
- Micro files

### Helpful Links:
- [Kodak FunSaver Disassembly](https://www.youtube.com/watch?v=eMyq5sUIDkU)

- [Kodak FunSaver Lens Removal](https://www.youtube.com/watch?v=mniP1P2PrpM)

- [Kodak FunSaver Lens Adapter Assembly](https://www.youtube.com/watch?v=7Ed5-oDCAb8)

### Printing help:
I print with PETG because it's pretty easy to set up with and dial in. If you want to use something else, go for it. I'd stay away from PLA because it's not the best in heat and against solvents. 

Generally, all my designs have chamfers on the print face of the STL.

Please view the printOrientation.3mf file for help with orienting the parts on the printer bed. 

### Assembly help:
Please view the _assembly.stp file for help in parts orientation. If you do not have a CAD program, <a href="https://www.freecad.org/downloads.php" target="_blank">download FreeCAD</a> to view the assembly file and better understand how it should assemble.

### Help support Archive 663 with a dontation or monthly sub


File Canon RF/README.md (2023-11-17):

## Kodak Funsaver lens rehousing for Canon RF

KFS_canonRF_1
KFS_canonRF_2
KFS_canonRF_3

### Features:
- Breech-lock mounting ring for DSLR/SLR cameras
- Standard mounting for Mirrorless cameras
- 30mm focal length
- Fixed ~f11 aperture
- Available in: Canon EF, EF-S, FD, RF; Fuji X; Leica M; M42; Nikon F DX, F FX, Z; Sony E

### What you’ll need:
- Lens from a Kodak FunSaver (2015 and newer)
- Viewfinder lenses from a Kodak FunSaver (2015 or newer) for
  
  [Kodak Funsaver Viewfinder Housing](https://github.com/Archive-663/kodakFunsaver/tree/main/viewFinder)
  
- [49mm Lens Cap](https://github.com/Archive-663/lensCaps)

### What would be helpful:
- digi-Process C-41 Lightroom Preset

    [Lightroom Presets](https://github.com/Archive-663/lightroomPresets)

    This preset develops your photos for a flat base reminiscent of old Kodak negative scans. It does not remove the distortion as it is a characteristic of the lens and of the photos that are produced with film. If you want to remove the distortion; set your distortion slider to ~ -12.

### Helpful Links:
- [Kodak FunSaver Disassembly](https://www.youtube.com/watch?v=eMyq5sUIDkU)

- [Kodak FunSaver Lens Removal](https://www.youtube.com/watch?v=mniP1P2PrpM)

- [Kodak FunSaver Lens Adapter Assembly](https://www.youtube.com/watch?v=7Ed5-oDCAb8)

### Printing help:
I print with PETG because it's pretty easy to set up with and dial in. If you want to use something else, go for it. I'd stay away from PLA because it's not the best in heat and against solvents. 

Generally, all my designs have chamfers on the print face of the STL.

Please view the printOrientation.3mf file for help with orienting the parts on the printer bed. 

### Assembly help:
Please view the _assembly.stp file for help in parts orientation. If you do not have a CAD program, <a href="https://www.freecad.org/downloads.php" target="_blank">download FreeCAD</a> to view the assembly file and better understand how it should assemble.

### Help support Archive 663 with a dontation or monthly sub


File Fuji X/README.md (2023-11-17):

## Kodak Funsaver lens rehousing for Fuji X

KFS_fujiX_1
KFS_fujiX_2
KFS_fujiX_3

### Features:
- Breech-lock mounting ring for DSLR/SLR cameras
- Standard mounting for Mirrorless cameras
- 30mm focal length
- Fixed ~f11 aperture
- Available in: Canon EF, EF-S, FD, RF; Fuji X; Leica M; M42; Nikon F DX, F FX, Z; Sony E

### What you’ll need:
- Lens from a Kodak FunSaver (2015 and newer)
- Viewfinder lenses from a Kodak FunSaver (2015 or newer) for
  
  [Kodak Funsaver Viewfinder Housing](https://github.com/Archive-663/kodakFunsaver/tree/main/viewFinder)
  
- [49mm Lens Cap](https://github.com/Archive-663/lensCaps)

### What would be helpful:
- digi-Process C-41 Lightroom Preset

    [Lightroom Presets](https://github.com/Archive-663/lightroomPresets)

    This preset develops your photos for a flat base reminiscent of old Kodak negative scans. It does not remove the distortion as it is a characteristic of the lens and of the photos that are produced with film. If you want to remove the distortion; set your distortion slider to ~ -12.

### Helpful Links:
- [Kodak FunSaver Disassembly](https://www.youtube.com/watch?v=eMyq5sUIDkU)

- [Kodak FunSaver Lens Removal](https://www.youtube.com/watch?v=mniP1P2PrpM)

- [Kodak FunSaver Lens Adapter Assembly](https://www.youtube.com/watch?v=7Ed5-oDCAb8)

### Printing help:
I print with PETG because it's pretty easy to set up with and dial in. If you want to use something else, go for it. I'd stay away from PLA because it's not the best in heat and against solvents. 

Generally, all my designs have chamfers on the print face of the STL.

Please view the printOrientation.3mf file for help with orienting the parts on the printer bed. 

### Assembly help:
Please view the _assembly.stp file for help in parts orientation. If you do not have a CAD program, <a href="https://www.freecad.org/downloads.php" target="_blank">download FreeCAD</a> to view the assembly file and better understand how it should assemble.

### Help support Archive 663 with a dontation or monthly sub


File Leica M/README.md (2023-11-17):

## Kodak Funsaver lens rehousing for Leica M

KFS_leicaM_1
KFS_leicaM_2
KFS_leicaM_3

### Features:
- Breech-lock mounting ring for DSLR/SLR cameras
- Standard mounting for Mirrorless cameras
- 30mm focal length
- Fixed ~f11 aperture
- Available in: Canon EF, EF-S, FD, RF; Fuji X; Leica M; M42; Nikon F DX, F FX, Z; Sony E

### What you’ll need:
- Lens from a Kodak FunSaver (2015 and newer)
- Viewfinder lenses from a Kodak FunSaver (2015 or newer) for
  
  [Kodak Funsaver Viewfinder Housing](https://github.com/Archive-663/kodakFunsaver/tree/main/viewFinder)
  
- [49mm Lens Cap](https://github.com/Archive-663/lensCaps)

### What would be helpful:
- digi-Process C-41 Lightroom Preset

    [Lightroom Presets](https://github.com/Archive-663/lightroomPresets)

    This preset develops your photos for a flat base reminiscent of old Kodak negative scans. It does not remove the distortion as it is a characteristic of the lens and of the photos that are produced with film. If you want to remove the distortion; set your distortion slider to ~ -12.

### Helpful Links:
- [Kodak FunSaver Disassembly](https://www.youtube.com/watch?v=eMyq5sUIDkU)

- [Kodak FunSaver Lens Removal](https://www.youtube.com/watch?v=mniP1P2PrpM)

- [Kodak FunSaver Lens Adapter Assembly](https://www.youtube.com/watch?v=7Ed5-oDCAb8)

### Printing help:
I print with PETG because it's pretty easy to set up with and dial in. If you want to use something else, go for it. I'd stay away from PLA because it's not the best in heat and against solvents. 

Generally, all my designs have chamfers on the print face of the STL.

Please view the printOrientation.3mf file for help with orienting the parts on the printer bed. 

### Assembly help:
Please view the _assembly.stp file for help in parts orientation. If you do not have a CAD program, <a href="https://www.freecad.org/downloads.php" target="_blank">download FreeCAD</a> to view the assembly file and better understand how it should assemble.

### Help support Archive 663 with a dontation or monthly sub


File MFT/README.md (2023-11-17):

## Kodak Funsaver lens rehousing for Micro Four Thirds

KFS_MFT_1
KFS_MFT_2
KFS_MFT_3

### Features:
- Breech-lock mounting ring for DSLR/SLR cameras
- Standard mounting for Mirrorless cameras
- 30mm focal length
- Fixed ~f11 aperture
- Available in: Canon EF, EF-S, FD, RF; Fuji X; Leica M; M42; Nikon F DX, F FX, Z; Sony E

### What you’ll need:
- Lens from a Kodak FunSaver (2015 and newer)
- Viewfinder lenses from a Kodak FunSaver (2015 or newer) for
  
  [Kodak Funsaver Viewfinder Housing](https://github.com/Archive-663/kodakFunsaver/tree/main/viewFinder)
  
- [49mm Lens Cap](https://github.com/Archive-663/lensCaps)

### What would be helpful:
- digi-Process C-41 Lightroom Preset

    [Lightroom Presets](https://github.com/Archive-663/lightroomPresets)

    This preset develops your photos for a flat base reminiscent of old Kodak negative scans. It does not remove the distortion as it is a characteristic of the lens and of the photos that are produced with film. If you want to remove the distortion; set your distortion slider to ~ -12.

### Helpful Links:
- [Kodak FunSaver Disassembly](https://www.youtube.com/watch?v=eMyq5sUIDkU)

- [Kodak FunSaver Lens Removal](https://www.youtube.com/watch?v=mniP1P2PrpM)

- [Kodak FunSaver Lens Adapter Assembly](https://www.youtube.com/watch?v=7Ed5-oDCAb8)

### Printing help:
I print with PETG because it's pretty easy to set up with and dial in. If you want to use something else, go for it. I'd stay away from PLA because it's not the best in heat and against solvents. 

Generally, all my designs have chamfers on the print face of the STL.

Please view the printOrientation.3mf file for help with orienting the parts on the printer bed. 

### Assembly help:
Please view the _assembly.stp file for help in parts orientation. If you do not have a CAD program, <a href="https://www.freecad.org/downloads.php" target="_blank">download FreeCAD</a> to view the assembly file and better understand how it should assemble.

### Help support Archive 663 with a dontation or monthly sub


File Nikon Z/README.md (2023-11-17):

## Kodak Funsaver lens rehousing for Nikon Z

KFS_nikonZ_1
KFS_nikonZ_2
KFS_nikonZ_3

### Features:
- Breech-lock mounting ring for DSLR/SLR cameras
- Standard mounting for Mirrorless cameras
- 30mm focal length
- Fixed ~f11 aperture
- Available in: Canon EF, EF-S, FD, RF; Fuji X; Leica M; M42; Nikon F DX, F FX, Z; Sony E

### What you’ll need:
- Lens from a Kodak FunSaver (2015 and newer)
- Viewfinder lenses from a Kodak FunSaver (2015 or newer) for
  
  [Kodak Funsaver Viewfinder Housing](https://github.com/Archive-663/kodakFunsaver/tree/main/viewFinder)
  
- [49mm Lens Cap](https://github.com/Archive-663/lensCaps)

### What would be helpful:
- digi-Process C-41 Lightroom Preset

    [Lightroom Presets](https://github.com/Archive-663/lightroomPresets)

    This preset develops your photos for a flat base reminiscent of old Kodak negative scans. It does not remove the distortion as it is a characteristic of the lens and of the photos that are produced with film. If you want to remove the distortion; set your distortion slider to ~ -12.

### Helpful Links:
- [Kodak FunSaver Disassembly](https://www.youtube.com/watch?v=eMyq5sUIDkU)

- [Kodak FunSaver Lens Removal](https://www.youtube.com/watch?v=mniP1P2PrpM)

- [Kodak FunSaver Lens Adapter Assembly](https://www.youtube.com/watch?v=7Ed5-oDCAb8)

### Printing help:
I print with PETG because it's pretty easy to set up with and dial in. If you want to use something else, go for it. I'd stay away from PLA because it's not the best in heat and against solvents. 

Generally, all my designs have chamfers on the print face of the STL.

Please view the printOrientation.3mf file for help with orienting the parts on the printer bed. 

### Assembly help:
Please view the _assembly.stp file for help in parts orientation. If you do not have a CAD program, <a href="https://www.freecad.org/downloads.php" target="_blank">download FreeCAD</a> to view the assembly file and better understand how it should assemble.

### Help support Archive 663 with a dontation or monthly sub


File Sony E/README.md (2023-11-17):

## Kodak Funsaver lens rehousing for Sony E (APSC + FF)

KFS_sonyE_1
KFS_sonyE_2
KFS_sonyE_3

### Features:
- Breech-lock mounting ring for DSLR/SLR cameras
- Standard mounting for Mirrorless cameras
- 30mm focal length
- Fixed ~f11 aperture
- Available in: Canon EF, EF-S, FD, RF; Fuji X; Leica M; M42; Nikon F DX, F FX, Z; Sony E

### What you’ll need:
- Lens from a Kodak FunSaver (2015 and newer)
- Viewfinder lenses from a Kodak FunSaver (2015 or newer) for
  
  [Kodak Funsaver Viewfinder Housing](https://github.com/Archive-663/kodakFunsaver/tree/main/viewFinder)
  
- [49mm Lens Cap](https://github.com/Archive-663/lensCaps)

### What would be helpful:
- digi-Process C-41 Lightroom Preset

    [Lightroom Presets](https://github.com/Archive-663/lightroomPresets)

    This preset develops your photos for a flat base reminiscent of old Kodak negative scans. It does not remove the distortion as it is a characteristic of the lens and of the photos that are produced with film. If you want to remove the distortion; set your distortion slider to ~ -12.

### Helpful Links:
- [Kodak FunSaver Disassembly](https://www.youtube.com/watch?v=eMyq5sUIDkU)

- [Kodak FunSaver Lens Removal](https://www.youtube.com/watch?v=mniP1P2PrpM)

- [Kodak FunSaver Lens Adapter Assembly](https://www.youtube.com/watch?v=7Ed5-oDCAb8)

### Printing help:
I print with PETG because it's pretty easy to set up with and dial in. If you want to use something else, go for it. I'd stay away from PLA because it's not the best in heat and against solvents. 

Generally, all my designs have chamfers on the print face of the STL.

Please view the printOrientation.3mf file for help with orienting the parts on the printer bed. 

### Assembly help:
Please view the _assembly.stp file for help in parts orientation. If you do not have a CAD program, <a href="https://www.freecad.org/downloads.php" target="_blank">download FreeCAD</a> to view the assembly file and better understand how it should assemble.

### Help support Archive 663 with a dontation or monthly sub


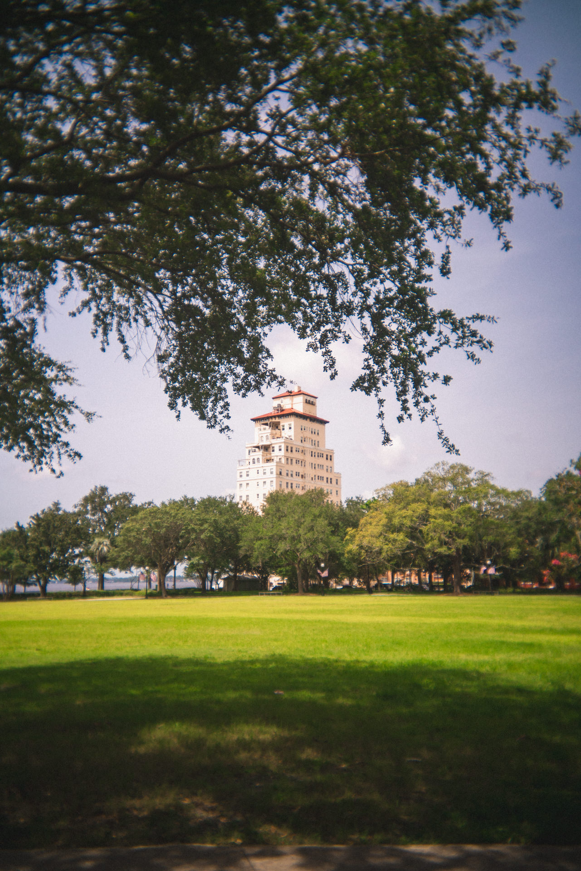
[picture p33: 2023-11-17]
ASSETS/kodakFunsaver_sample (20).jpg

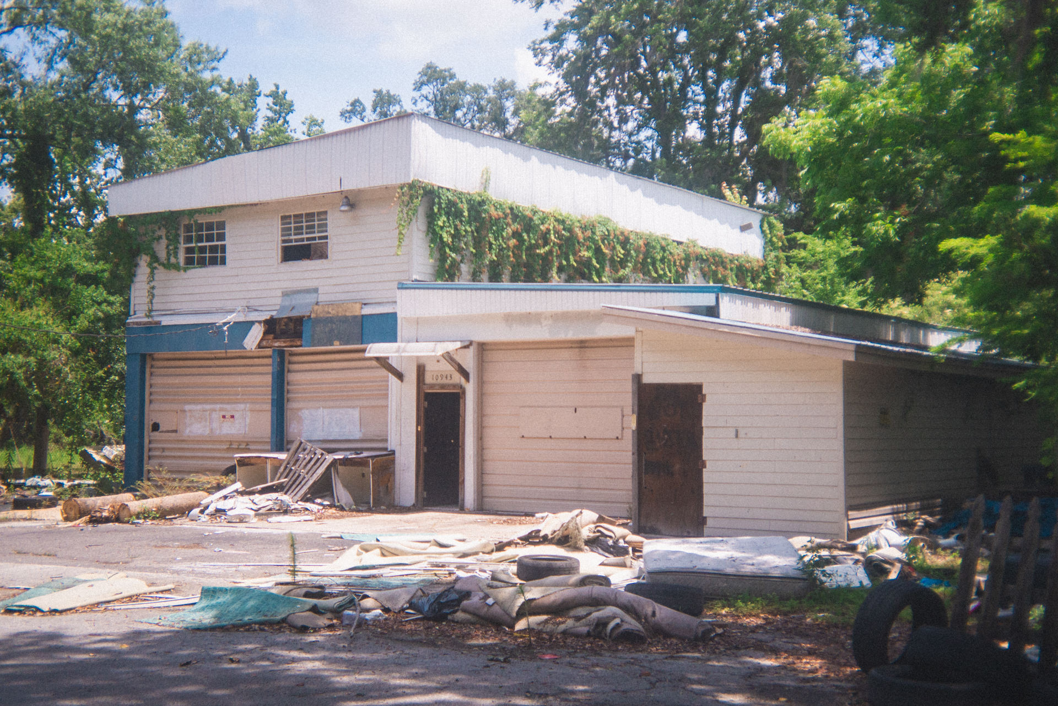
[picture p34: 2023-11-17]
ASSETS/kodakFunsaver_sample (5).jpg

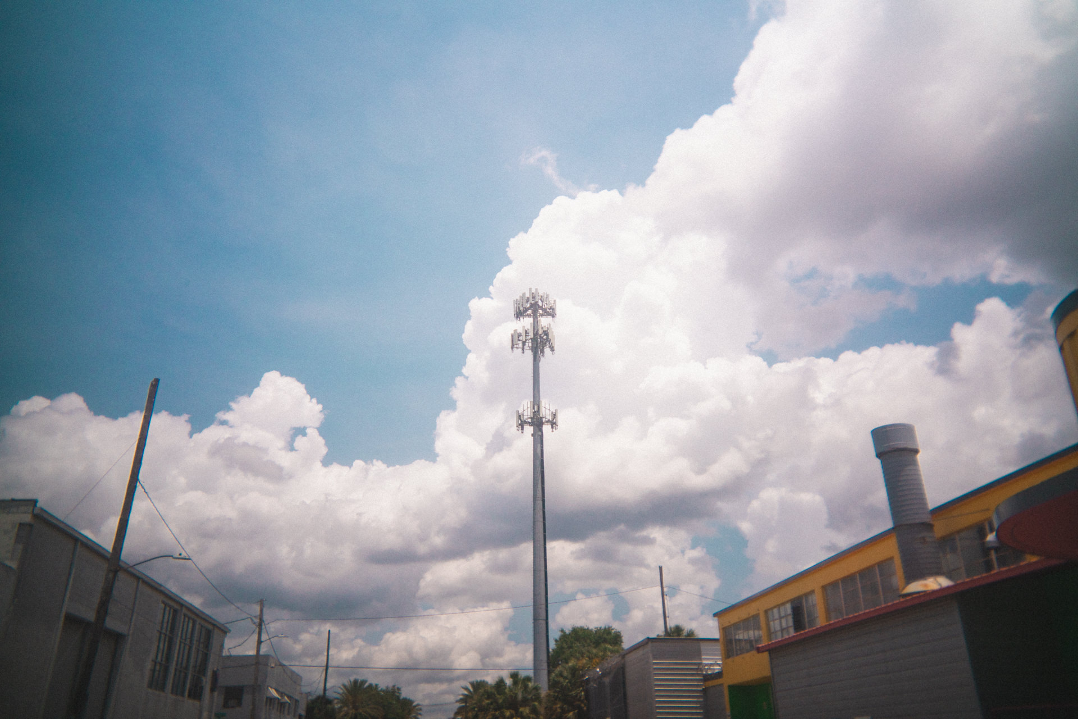
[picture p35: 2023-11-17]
ASSETS/kodakFunsaver_sample (6).jpg

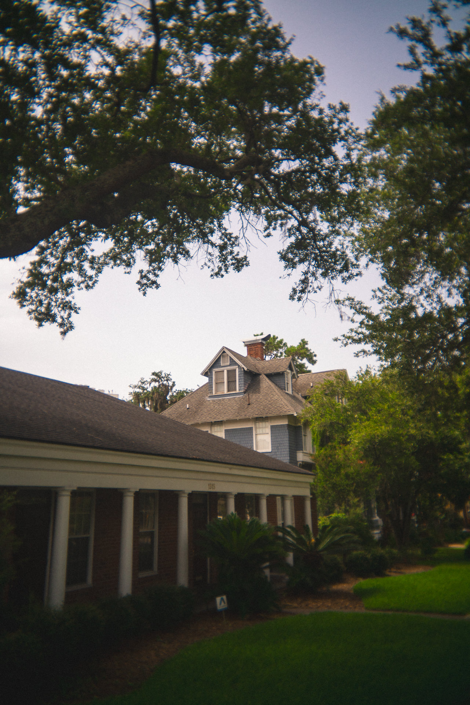
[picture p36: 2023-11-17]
ASSETS/kodakFunsaver_sample (19).jpg

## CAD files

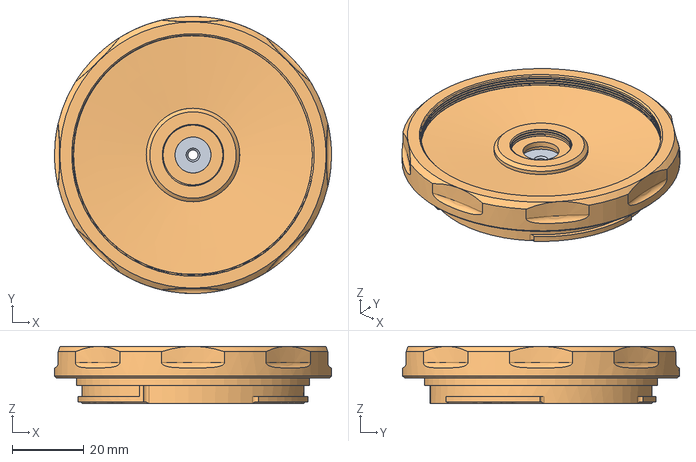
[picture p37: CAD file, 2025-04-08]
Fuji GFX/STEP/kodakFunsaver_fujiGFX_assembly.stp
77.0 x 77.0 x 16.0 mm
kodakFunsaver_lensLock
kodakFunsaver_fujiGFX_body

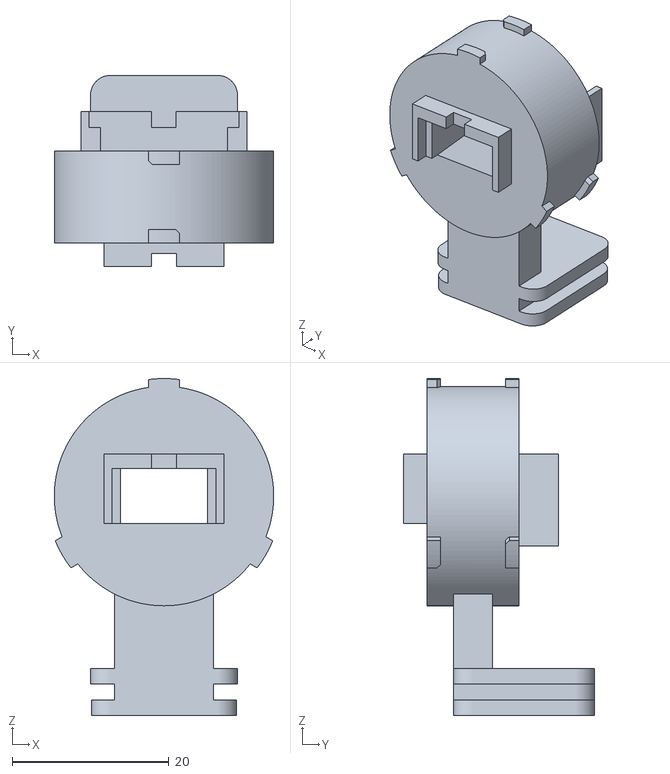
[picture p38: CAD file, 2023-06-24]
viewFinder/viewFinder_round/STL/kodakFunsaver_viewFinder_mainBody.stl
28.0 x 24.4 x 43.0

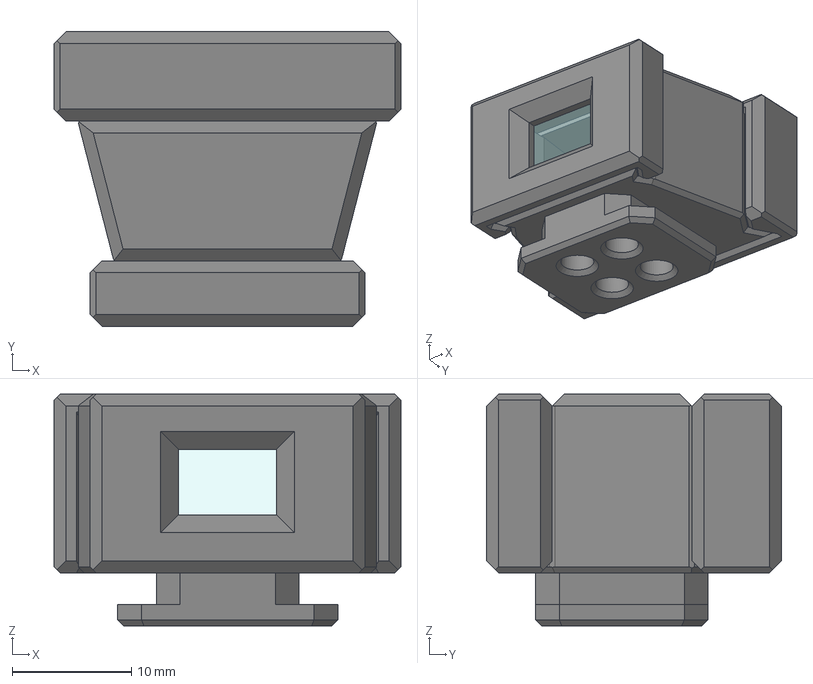
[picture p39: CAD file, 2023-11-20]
viewFinder/viewFinder_SQ/STEP/kodakFunsaver_viewFinder_SQ_assembly.stp
29.1 x 24.8 x 19.4 mm
kodakFunsaver_viewFinder_mainBody
kodakFunsaver_viewFinder_frontLens
kodakFunsaver_viewFinder_rearLens
kodakFunsaver_viewFinder_frontCap
kodakFunsaver_viewFinder_rearCap
kodakFunsaver_viewFinder_coldShoe

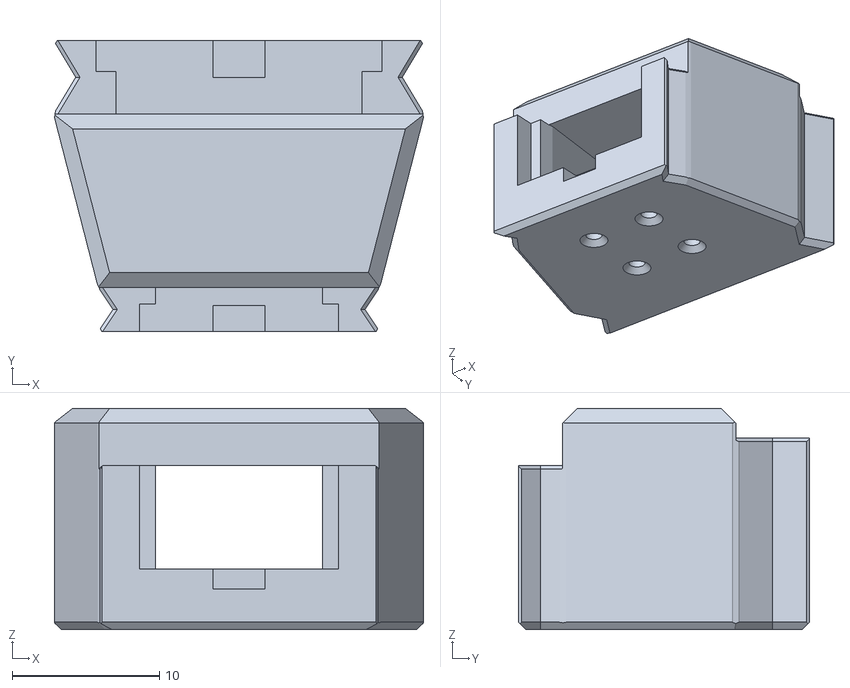
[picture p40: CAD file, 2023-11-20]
viewFinder/viewFinder_SQ/STL/kodakFunsaver_viewFinder_mainBody.stl
25.0 x 19.8 x 15.0

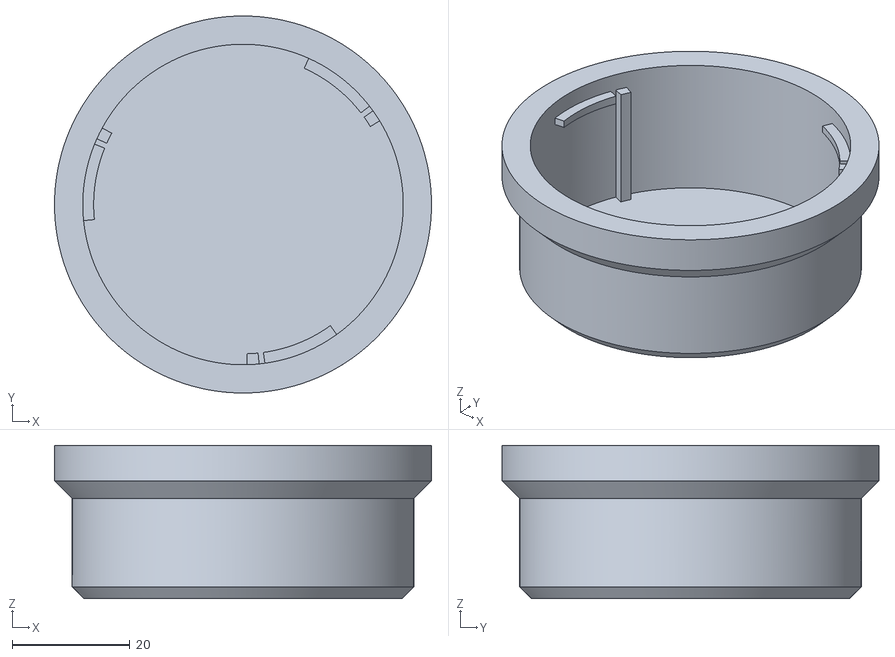
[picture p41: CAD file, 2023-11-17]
Canon EF-S/STL/baseRearCap_canonEF_KFS.stl
64.0 x 64.0 x 26.0

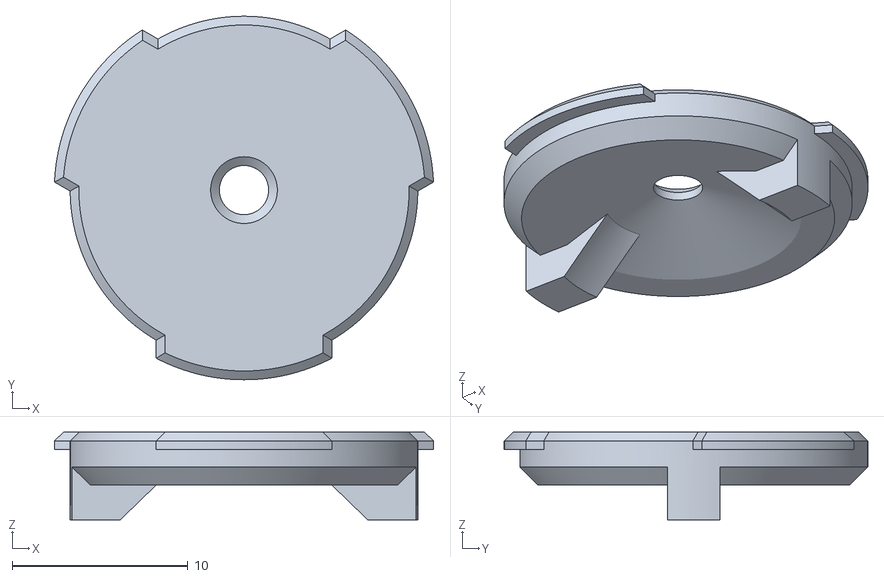
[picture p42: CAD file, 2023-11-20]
Canon EF/STL/kodakFunsaver_lensLock.stl
21.6 x 20.7 x 5.00

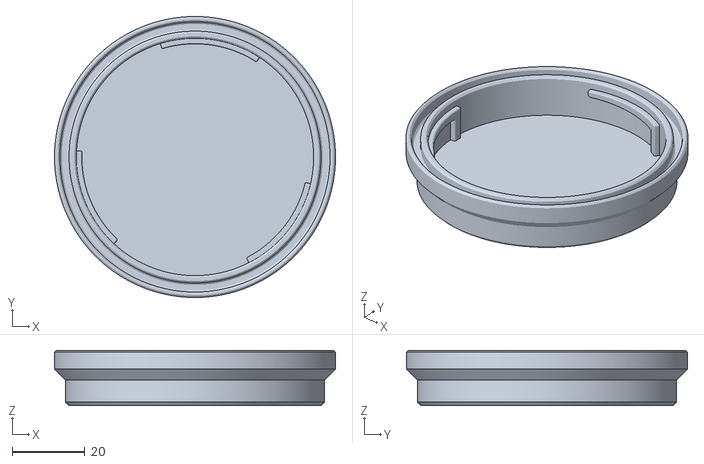
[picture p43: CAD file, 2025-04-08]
Fuji GFX/STL/mountRearCapGFX.stl
77.0 x 77.0 x 15.1

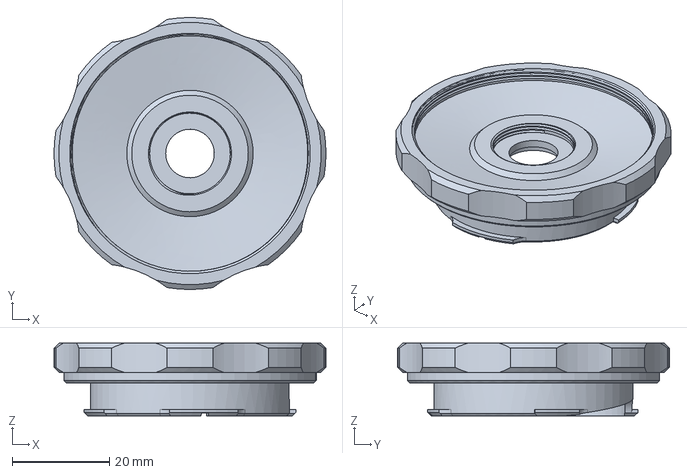
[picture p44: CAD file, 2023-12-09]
Leica M/STEP/kodakFunsaver_leicaM_body.stp
56.0 x 56.0 x 14.9 mm

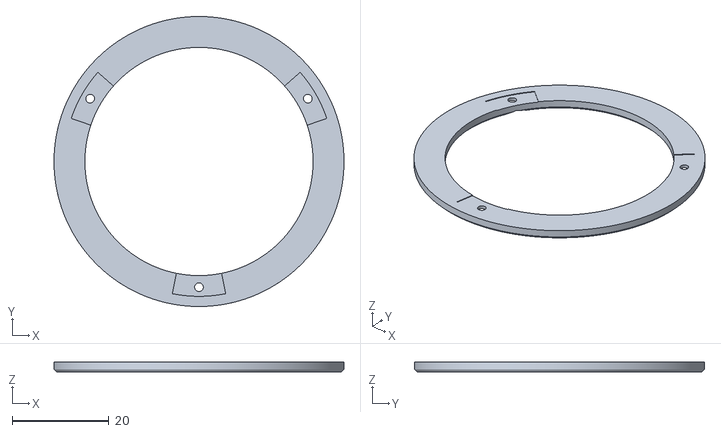
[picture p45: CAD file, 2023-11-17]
Nikon F DX/STL/nishiKodak_nikonF-FX_mountCap.stl
60.0 x 60.0 x 2.00

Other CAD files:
viewFinder/viewFinder_SQ/STEP/kodakFunsaver_viewFinder_SQ_mainBody.stp
Canon EF-S/STL/kodakFunsaver_canonEF-S_lensLock.stl
Canon EF-S/STL/kodakFunsaver_canonEF-S_printOrientation.3mf
Canon EF-S/STL/nishiKodak_canonEF_mountCap.stl
Canon EF-S/STL/nishiKodak_canonEF_mountFlange.stl
Canon EF-S/STL/nishiKodak_canonEF_mountLockRing.stl
Canon EF/STL/kodakFunsaver_canonEF_printOrientation.3mf
Canon EF/STL/nishiKodak_canonEF_mountCap.stl
Canon EF/STL/nishiKodak_canonEF_mountFlange.stl
Canon EF/STL/nishiKodak_canonEF_mountLockRing.stl
Canon FD/STL/baseRearCap_canonFD_KFS.stl
Canon FD/STL/kodakFunsaver_canonFD_printOrientation.3mf
Canon FD/STL/nishiKodak_canonFD_breechLock.stl
Canon RF/STL/baseRearCap_canonRF.stl
Canon RF/STL/kodakFunsaver_canonRF_printOrientation.3mf
Fuji GFX/STEP/fujiGFX_rearCap.stp
Fuji GFX/STEP/kodakFunsaver_fujiGFX_body.stp
Fuji GFX/STEP/kodakFunsaver_lensLock.stp
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

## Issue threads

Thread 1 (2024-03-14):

Too Deep For DSLR

TarrynVenneTodd, 2024-03-14:
I am a little confused and hope Im not making a fool of myself by missing something super simple lol. I have printed the EF and EF-S mount for my Canon T5i DSLR. I find that when I go to attach the printed assembly to my camera, the body is too deep and might as well be touching my mirror in my camera. Is there something I am missing?

Let me know if you have any solutions! Thanks.

gmoua663, 2024-04-22:
Hey, Tarryn.

For it to work on DSLRs you need to put it in Mirror Lock up mode. The flange focal distance is too short on these disposable camera lenses to fit in front of the mirror like a standard lens. Once in Mirror Lock Up you won't be able to see through the viewfinder so you'll have to print this: https://github.com/Archive-663/kodakFunsaver/tree/main/viewFinder and cannibalize the viewfinder from the Kodak Funsaver.

https://www.dummies.com/article/home-auto-hobbies/photography/cameras/canon/how-to-enable-mirror-lockup-on-the-rebel-t5i-162131/

It's a risk, so if you're unsure of using it I'd play it cautiously and not use it. I've used my old Canon Rebel XT to test the lens and it works fine for me.

gmoua663, 2024-04-22:
Oof, I thought I mentioned it in the description but it looks like I omitted it from this version. I'll update the need for Mirror Lock up on DSLRs.

Apologies.

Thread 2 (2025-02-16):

Canon EF-S Lens Mount doesn't fit

DanielWilk09, 2025-02-16:
Hi George,

I 3D printed the EF-S lens mount for the kodak funsaver and unfortunately it doesn't fit. The jpg on the readme and the example photo of your camera in the assets look great however they look quite different. I wondered if there had been an update to the files that may have made it not fit. I am using a Rebel T7 / 2000D.

Thanks,
Daniel

gmoua663, 2025-03-01:
Hey, Daniel.

There shouldn't have been an update. Can you give me a rundown on how you're mounting the lens? If possible, have you verified the printing dimension with the one pulled from the STEP files? You can download FreeCAD to measure dimensions to compare them with the physical printed dimensions.

I'm looking at photos of the mirror box on the T7 and the XT (the camera I tested it on) and I can't see much of a difference. I may have to pick one up to see where the issue it.

Appreciate you bringing up this issue. Let me know the above if you have the time and a set of digital calipers.

Cheers,
George

DanielWilk09, 2025-03-02:
Hi George,

Thanks for taking the time to reply. Reading my message back I have realised that I wasn’t actually very clear, it’s not the lens from the Kodak that doesn’t fit (I actually haven’t got it get because I wanted to see if the mount fits first) but it’s the mount that doesn’t fit. I didn’t change any dimensions and the file printed is accurate to the STL/STEP. The photos show what I mean much easier than words could but in those photos it is as far into the camera body as possible meaning maybe the far back rectangle where the actual lens gets mounted is too big. I hope that made a bit of sense.

Thanks,
Daniel

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

gmoua663, 2025-03-03:
Hey, Daniel.

So a couple of things. You're printing on the wrong side. If you download the .3mf file you'll see how I layout the print. Without actual measurements from a caliper it's hard to tell what else is going on, but visually, what I see is that you're printing the rear down first you're getting elephant's foot which is going to not allow you to mount the lens. Also because you're printing upside-down, it's going to be difficult to mate and assemble the rest of the parts of the lens. The drooping caused by the overhangs on supports is going to give you additional thickness where there shouldn't be any.

When you go to mount, are you in mirror lock up mode on the T7?

How dialed in is your printer? With a 20 x 20 x 20 cube is it relatively in spec?

Cheers,
George

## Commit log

2023-06-24 CREATE kodakFunsaver EFS
    [kodakFunsaver_canonEFS_Latch L.step, kodakFunsaver_canonEFS_Latch L.stl, kodakFunsaver_canonEFS_Latch R.step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]
2023-06-24 Add Viewfinder STL
    [Kodak Range Finder 004_Front Cap.stl, Kodak Range Finder 004_Front Sight.stl, Kodak Range Finder 004_Main Body.stl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]
2023-06-27 Add Leica M
    [kodakFunsaver_LeicaM_Lens Body.stl, kodakFunsaver_LeicaM_Lens Lock.stl]
2023-11-17 Uploaded more mounts
    Canon EF, EF-S, FD, RF; Fuji X; Leica M; M42; Nikon F DX, F FX, Z; Sony E
    [Kodak Range Finder 004_Front Cap.stl, Kodak Range Finder 004_Front Sight.stl, Kodak Range Finder 004_Main Body.stl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]
2023-11-20 update files
    Updated Leica M body, base Lens Lock. Added Square viewfinder.
    [kodakFunsaver_leicaM_body.stl, kodakFunsaver_lensLock.stl, kodakFunsaver_viewFinder_SQ_assembly.stp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]
2023-11-20 upload sample photos
2023-12-09 Guh, updating step files
    separating STEP exports so it's not the entire design in one file.
    [kodakFunsaver_leicaM_body.stp, kodakFunsaver_lensLock.stp]
2025-04-08 upload GFX
    [fujiGFX_rearCap.stp, kodakFunsaver_fujiGFX_assembly.stp, kodakFunsaver_fujiGFX_body.stp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]
